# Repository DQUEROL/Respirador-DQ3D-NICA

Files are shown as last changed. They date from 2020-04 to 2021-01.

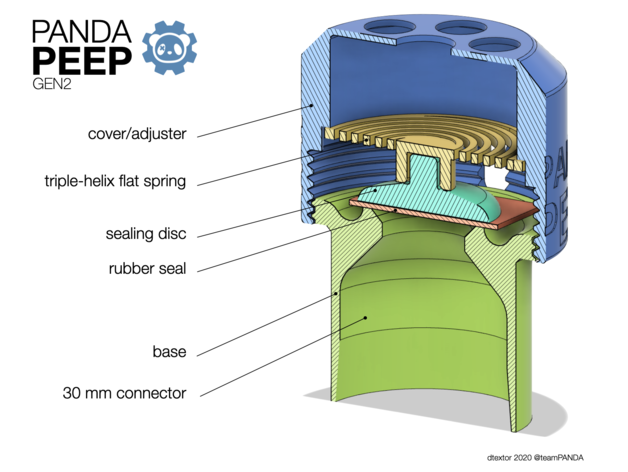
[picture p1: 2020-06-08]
03 Accesorios, valvulas, sensores/peep/PANDApeep+Gen2+PEEP+valve/images/PANDApeep_gen2.png

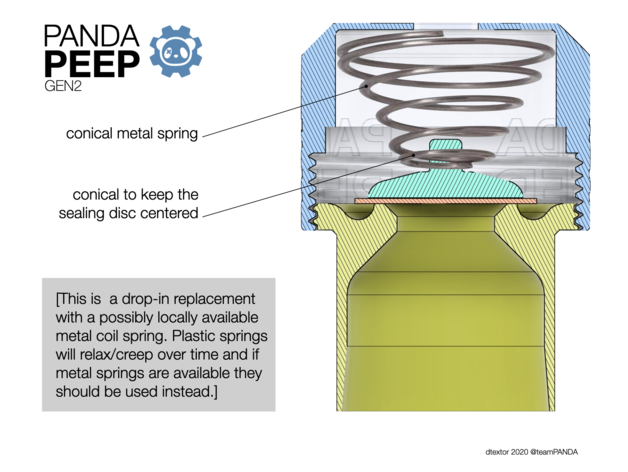
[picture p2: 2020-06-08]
03 Accesorios, valvulas, sensores/peep/PANDApeep+Gen2+PEEP+valve/images/Screenshot_2020-04-04_at_11.43.28.png

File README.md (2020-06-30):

# Apoyo respiratorio DQ3D para CoViD-19

Daniel Querol

Nicaragua, 28 04 2020

(https://www.youtube.com/watch?v=0zzoeBUPshY)

## El porqué de este Respirador

Nicaragua es el segundo país más pobre de América, y tiene un sistema de salud que, a falta de recursos, funciona con una mezcla de sobreesfuerzo del personal médico y mecanismos folclóricos para enfrentar patologías.

Frente a la COVID-19 y con recursos muy limitados, el gobierno ha asumido una posición fatalista para el conjunto de la población. Hasta la fecha se han reportado trece casos. Al igual que en el resto del mundo, es de esperarse que, con la curva epidemiológica conservadora planteada por el MINSA, en Nicaragua se presentarán al menos 32,000 casos en los próximos 180 días, de los cuales 8,000 serán graves y pasarían a cuidados intensivos. En todo el país hay menos de 150 respiradores, la mayor parte de los cuales están reservados. No se conoce de un plan de compra de respiradores, y tampoco existe el personal capacitado para manejarlos.

Los primeros análisis médicos estiman que sólo un 10 a 20% de los pacientes sometidos a intubación mecánica consigue recuperarse, y con secuelas a corto y largo plazo.

En la coyuntura actual parece razonable construir algún tipo de respirador que permita **respiración asistida** , ya que la **respiración controlada** incluye sedación, intubado y monitoreo, lo cual sólo puede ser hecho por un médico preparado y en condiciones hospitalarias. 

Para las condiciones de Nicaragua y de muchos otros países pobres, es necesario diseñar un equipo que permita dar respiración asistida (sin necesaria supervisión médica directa, por ejemplo vía telemedicina) y cuyos costos sean bajos, que sea robusto y con componentes fácilmente disponibles.
El equipo actualmente se puede considerar de la categorìa **BiPAP**.

## Estructura de directorios

[Descripción completa del equipo y proceso de seleccion de caracteristicas y componentes](https://github.com/DQUEROL/Respirador-DQ3D-NICA/blob/master/Equipo%20apoyo%20respiratorio%20v2.docx)

[00 Diseño](https://github.com/DQUEROL/Respirador-DQ3D-NICA/tree/master/00%20Dise%C3%B1o)            Piezas para corte laser e impresion 3D

[01 AMBUs](https://github.com/DQUEROL/Respirador-DQ3D-NICA/tree/master/01%20AMBUs)             Diferentes modelos de AMBU utilizados en proyectos

[02 Motores y driver](https://github.com/DQUEROL/Respirador-DQ3D-NICA/tree/master/02%20Motores%20y%20driver)  Motores utilizados y caracteristicas

[03 Accesorios, valvulas, sensores](https://github.com/DQUEROL/Respirador-DQ3D-NICA/tree/master/03%20Accesorios%2C%20valvulas%2C%20sensores) Informaciòn de los sensores revisados y utilizados, incluye PEEP.

[04 Electronica](https://github.com/DQUEROL/Respirador-DQ3D-NICA/tree/master/04%20Electronica%20y%20firmware)       **Diseño y sketch Arduino**

[05 Fotos y Videos ](https://github.com/DQUEROL/Respirador-DQ3D-NICA/tree/master/05%20Fotos%20y%20videos)

[06 Revisiones y Testing](https://github.com/DQUEROL/Respirador-DQ3D-NICA/tree/master/06%20Revisiones%20y%20Testing)   **Ultimas actualizaciones**

[Información clínica](https://github.com/DQUEROL/Respirador-DQ3D-NICA/tree/master/Informacion%20clinica)

[Manuales de otros ventiladores y respiradores](https://github.com/DQUEROL/Respirador-DQ3D-NICA/tree/master/Manuales%20de%20ventiladores%20y%20respiradores)

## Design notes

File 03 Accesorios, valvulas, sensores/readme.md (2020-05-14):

Sensores

Presion
https://www.allaboutcircuits.com/technical-articles/electrical-engineer-using-pressure-sensor-adjust-oxygen-concentration-mechanical-ventilation/

Volumen y flujo
Pressure Airflow Measure Device with Analog Sensor - Arduino Project Hub
https://create.arduino.cc/projecthub/itmightbeworse/pressure-airflow-measure-device-with-analog-sensor-037d15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

Humedad, temperatura y presión	BMP280

Gauge & Differential Pressure Sensors SMI
https://www.mouser.com/datasheet/2/589/SM6X21_Datasheet-1287040.pdf

Humedad y temperatura	DHT22
	
Biomonitor

  Pulso, Oxigenación, Temperatura

Valvulas
Download free 3D printer designs ventilator valves 3d model � Cults
https://cults3d.com/en/3d-model/gadget/ventilator-valves-3d-model-shawnshroff

Interfases (pantallas y encoders)
Encoder Library, for Measuring Quadarature Encoded Position or Rotation Signals
https://www.pjrc.com/teensy/td_libs_Encoder.html

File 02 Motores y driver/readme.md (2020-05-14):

Links anotados

5X CNC Single Axis 4A TB6600 24 Phase Hybrid Stepper Motor Drivers Controller eBay
URL=https://www.ebay.com/itm/5X-CNC-Single-Axis-4A-TB6600-2-4-Phase-Hybrid-Stepper-Motor-Drivers-Controller/133288683688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

TB6600 Stepper Motor driver Tester - Hackster.io
https://www.hackster.io/ashleyblack/tb6600-stepper-motor-driver-tester-85a29e

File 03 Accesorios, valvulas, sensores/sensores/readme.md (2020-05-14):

Links anotados

Ideas basicas
https://hackaday.io/project/170782-precision-ventilator
https://derangedphysiology.com/main/cicm-primary-exam/required-reading/respiratory-system/Chapter%20509/sensors-monitoring-mechanical-ventilation

Paquete para montaje
https://hackaday.io/project/170622-visp-ventilator-inline-sensor-package

Flow Sensor Solutions in Modern Medical Ventilators 
Sensirion
https://www.sensirion.com/en/about-us/newsroom/sensirion-specialist-articles/flow-sensor-solutions-in-modern-medical-ventilators/

AMPHENOL
https://www.piher.net/sensors/index.php?Itemid=1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

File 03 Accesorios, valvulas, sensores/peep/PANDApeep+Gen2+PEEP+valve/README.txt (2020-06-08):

PANDApeep Gen2 PEEP valve by dtextor on Thingiverse: https://www.thingiverse.com/thing:4250354

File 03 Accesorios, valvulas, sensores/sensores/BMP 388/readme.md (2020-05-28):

Links anotados

Comparacion de sensores sencillos
https://randomnerdtutorials.com/dht11-vs-dht22-vs-lm35-vs-ds18b20-vs-bme280-vs-bmp180/

https://goughlui.com/2018/08/05/note-bosch-sensortec-bmp280-vs-bme280-sensor-confusion/

USO del BMP280
Para usar dos sensores BMP280 en I2C, la direccion es 0x76 normalmente (SDO = 0v) y 0x77 cuando se conecta SDO a 3.3v.

https://github.com/snipe75/low-cost-medical-ventilator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

https://www.bosch-sensortec.com/products/environmental-sensors/pressure-sensors/pressure-sensors-bmp280-1.html

https://www.esp8266.com/viewtopic.php?f=13&t=18141&start=8

Uso en Arduino, BME280 non blocking
https://github.com/finitespace/BME280#settings

An Arduino compatible, non-blocking, I2C/SPI library for the Bosch BMP280 barometer.
https://github.com/MartinL1/BMP280_DEV

Next generation BMP388
https://www.mouser.com/datasheet/2/783/BST-BMP388-DS001-1509617.pdf

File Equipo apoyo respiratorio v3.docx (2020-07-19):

Apoyo respiratorio DQ3D para Covid-19

DQ3D-NICA BiPAP

Daniel Querol

Nicaragua, 28 05 2020

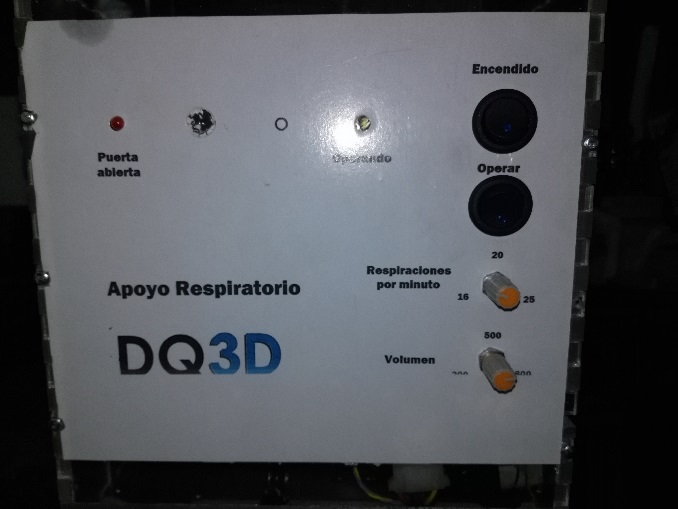
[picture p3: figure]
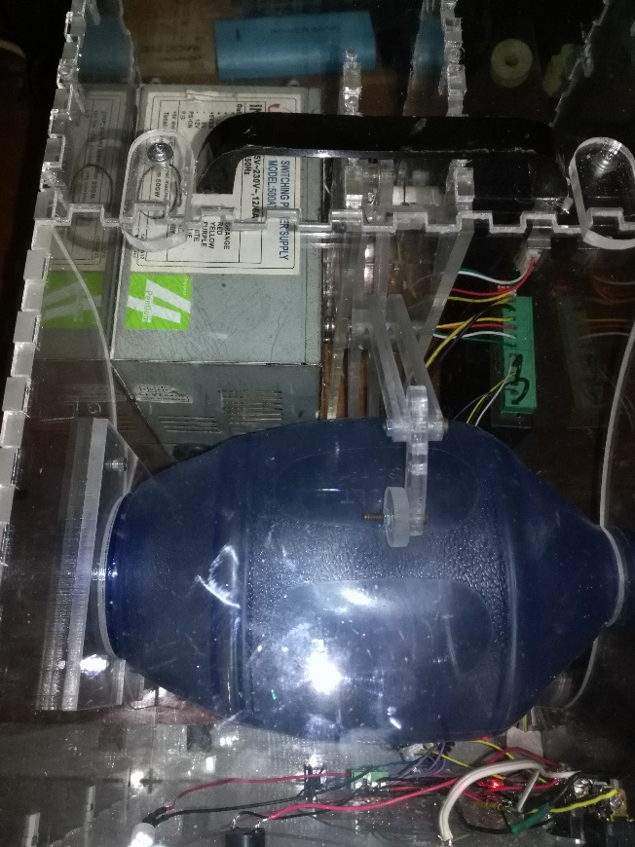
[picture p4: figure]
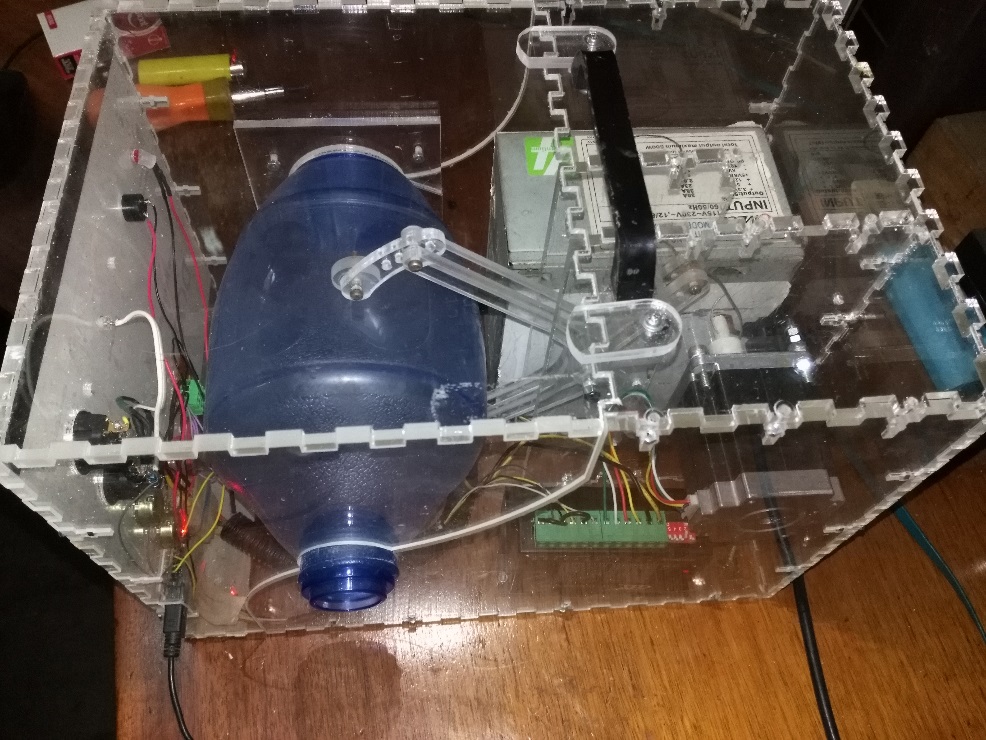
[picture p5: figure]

Contenido

# 1 Conceptos y objetivos

## 1.1 El porqué de este Respirador

Nicaragua es el segundo país más pobre de América, y tiene un sistema de salud que, a falta de recursos, funciona con una mezcla de sobreesfuerzo del personal médico y mecanismos folclóricos para enfrentar patologías.

Frente a la COVID-19 y con recursos muy limitados, el gobierno ha asumido una posición fatalista para el conjunto de la población. Hasta la fecha se han reportado trece casos. Al igual que en el resto del mundo, es de esperarse que, con la curva epidemiológica conservadora planteada por el MINSA, en Nicaragua se presentarán al menos 32,000 casos en los próximos 180 días, de los cuales 8,000 serán graves y pasarían a cuidados intensivos. En todo el país hay menos de 150 respiradores, la mayor parte de los cuales están reservados. No se conoce de un plan de compra de respiradores, y tampoco existe el personal capacitado para manejarlos.

Los primeros análisis médicos [^1], [^2], [^3] estiman que sólo un 10 a 20% de los pacientes sometidos a intubación mecánica consigue recuperarse, y con secuelas a corto y largo plazo.

En la coyuntura actual parece razonable construir algún tipo de respirador que permita respiración asistida (BiPAP) , ya que la respiración controlada incluye sedación, intubado y monitoreo, lo cual sólo puede ser hecho por un médico preparado y en condiciones hospitalarias.

Para las condiciones de Nicaragua y de muchos otros países pobres, es necesario diseñar un equipo que permita dar respiración asistida (sin necesaria supervisión médica directa, por ejemplo vía telemedicina) y cuyos costos sean bajos, que sea robusto y con componentes fácilmente disponibles.

## 1.2 Selección de componentes

En base a lo anterior, se diseñó un equipo basado en componentes reciclados disponibles de impresoras y computadores, con una estructura de soporte hecha en acrílico cortado con láser, pero que podría hacerse con madera contrachapada.

Hay muchos prototipos creados por cientos de voluntarios en todo el mundo, de los cuales se retomaron ideas y conceptos, en un verdadero esfuerzo de colaboración internacional. Se analizaron varios prototipos preexistentes (Anexo 1) de una lista mundial de procesos de trabajo (https://docs.google.com/spreadsheets/d/e/2PACX-1vTYAfldxoIiO46VAWH1NlhrwFBn9mguqS2bh1spnLEu4AVVN1cj1vaEm6vOp5Z6UnaAbUwd8dslCXdM/pubhtml).

Durante la fase de selección de opciones a inicios de marzo, se valoraron las propuestas planteadas y se tomaron algunas decisiones:

- Los componentes deben ser económicos y de fácil disponibilidad.
- Las piezas mecánicas y estructurales adicionales deben ser cortadas y no impresas en 3D, ya que las impresoras 3D no están disponibles para todos, todavía.
- Los motores de limpiaparabrisas para presionar el AMBU usados en muchos diseños tienen mucha fuerza, pero no están diseñados para uso continuo durante días.
- Los diseños con uso de levas (discos) excéntricas no permiten regular volumen variable de aire.
- La velocidad y posición de motores clásicos (AC y DC) no pueden ser controlados con precisión. Y no se pueden mantener con fuerza en un punto fijo (Meseta).
- El uso de una caja de cambios o reductor de velocidad hace más difícil la producción de componentes o más alto el costo. Los motores con caja incorporada no son de fácil ubicación.
- Hay que minimizar el desperdicio de potencia, para poder reducir el tamaño del motor. Para ello:
  - La presión sobre el AMBU debe ser bilateral y simétrica.
  - Se deben minimizar las pérdidas de energía durante la transmisión
  - El ángulo de ataque de la pieza de presión determinará su buen funcionamiento

### 1.2.1 Componentes y conceptos utilizados

(Ver Anexo 2: detalles técnicos)

Componentes y conceptos utilizados (ver lista con detalles técnicos) Componente | Link | Tipo | Notas
Resucitador Ambulatorio AMBU | | Nuevo | 1
Fuente de poder | ATX-PSU de PC (https://en.wikipedia.org/wiki/Power_supply_unit_(computer)) | Reciclado | 2
Motor de pasos NEMA23 | 2.4 A, 13.9Kg.cm (1.36Nm) (https://www.ebay.com/itm/New-Nema-23-Stepper-motor-Sanyo-Denki-142-ozin-CNC-ROUTER-MILL-LATHE-ROBOT-0666/121701679248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) | Reciclado | 3
Arduino Nano | Nano (https://www.ebay.com/itm/Mini-USB-Nano-V3-0-ATmega328P-5V-16M-Micro-Controller-Board-for-Arduino/174120707751) | Nuevo | 4
Driver Motor | 5 Amp TB6600 (https://www.ebay.com/itm/CNC-Single-Axis-TB6600-0-2-5A-Two-Phase-Hybrid-Stepper-Motor-Driver-Controlle/254581090595) | Nuevo | 5

Notas

1. Resucitador (respirador) Ambulatorio AMBU (chimbomba)

Descripción Adulto

Volumen tidal 700 ml

Peso del paciente > 30 kg

Volumen total de la bolsa 1475 ml

Dimensiones (longitud x diámetro) 291 mm x 128 mm

Volumen de la bolsa del depósito de O2 2600 ml

Conector externo del paciente 22 mm (ISO)

Conector interno del paciente 15 mm (ISO)

Conector espiratorio (para válvula PEEP) 30 mm macho (ISO)

- Apretando con una mano 650ml, 110mm
- Ambos lados 800ml, 120mm
- AMBU son 128mm a 131 mm de diámetro en modelos en línea
2. Las fuentes de poder ATX son utilizadas en la mayor parte de las computadoras, y son de fácil disponibilidad, económicas, robustas y estables. Además tienen 5v y 12v.
3. El motor de pasos NEMA23 se encuentra en muchos equipos de oficina, son potentes y robustos, y permiten control preciso de posición y velocidad.
4. El Arduino Nano, tiene suficiente memoria y capacidad de procesamiento para este equipo, siendo muy económico y robusto.
5. Estos driver son de fácil disponibilidad y económicos.

# 2 Especificaciones clínicas del Respirador DQ3D-NICA

## 2.1 Recomendaciones clínicas del Dr. Karil Barquero

  - Frecuencia: 16 a 25 respiraciones por minuto (rango continuo)
    - Buscar mecanismo para sincroniza con respiración del paciente
      - 30 por minuto hiperventilando, sedar, diazepan, de allí declinar
  - Tiempo relativo del ciclo aspira/espira: 1:1 – 1:3
    - Finalmente, fracción inspiratoria de .42
  - Volumen marea regulable de 200 a 700 cc
  - Válvula mecánica sobrepresión 40 a 60 cm.H2O
  - Alarma
  - Posibilidad de extracción rápida para manejo manual
  - Sensores Temperatura, Humedad Relativa
    - Temp max : 40 C
    - HR: min 32%, max 50%
  - Sensores de presión si se puede

## 2.2 Otros datos

Se retomaron las especificaciones mínimas de MIT. (https://e-vent.mit.edu/clinical/key-ventilation-specifications/)

Se utilizó el trabajo de Chaparro y Giraldo (2011)[^4] para para la determinación de valores óptimos, para una buena recuperación.

Variables respiratorias (http://www.scielo.org.co/scielo.php?script=sci_arttext&pid=S1909-97622011000100007&lng=en&nrm=iso&tlng=es) | | Mejor | Unidad
duración del ciclo respiratorio | TTot | 2.79 | s
tiempo de inspiración | TI | 1.09 | s
tiempo de espiración | TE | 1.69 | s
volumen tidal | VT | 622 | cc
fracción inspiratoria | TI/TTot | 0.42
flujo inspirado medio | VT/TI | 629 | cc/s
índice de respiración superficial | f/VT | 70 | Resp/min/l | siendo f la frecuencia respiratoria

# 3 Equipo de apoyo respiratorio

El equipo propuesto, en su versión 3.0, tiene las siguientes características:

Función | Rango | Cambiable vía | Fijada
Volumen aire | 200 a 600 cc | Tablero | No
Respiraciones por minuto | 16 a 25 RPM | Tablero | No
Fracción inspiratoria | 0.42 | Firmware | Si
Meseta | 500 milisegundos | Firmware | Si
Pausa al final marea | 0 | Firmware | Si
Medición de presión y temperatura | Cada 100 milisegundos | Firmware | Si
Válvula mecánica sobrepresión | 35cmH2O | NO | Si
Salto de pasos por sobrepresión | 30cmH2O | NO | SI
Conexión a oxigeno | Disponible
Alarmas | varias fallas mecánica, presión, etc
1= falla de motor/origen, | pasos | Firmware | Si
2= Falla de origen del brazo, | pasos | Firmware | Si
3= Exceso de presión | 30cmH2O | Firmware | Si
4= Presión demasiado baja | -5cmH2O | Firmware | Si
5= Sobre temperatura | 39C | Firmware | Si
6= Sensor presión desconectado | | Firmware | Si

La conexión del equipo a la mascarilla se hace, dependiendo de la manguera disponible, con dos adaptadores impresos en 3D. En Nicaragua solo se obtuvo una manguera de PVC de 19mmØ, utilizada para cableado interno en construcciones.

La extracción del AMBU para uso manual es sencilla.

No hubo calentamiento durante las 192 horas continuas que el equipo estuvo funcionando, por lo que la temperatura no necesita ser controlada.

La humedad del aire, de ser necesario, puede ser aumentada con el uso de un frasco con agua en la manguera entre el equipo y la mascarilla.

## 3.1 Lógica de operación

El usuario enciende el equipo, y se inician calibraciones y definición de punto de origen

El usuario enciende el apoyo respiratorio (Operar). El equipo lee los valores de volumen y RPM e inicia la respiración. Después de cada respiración se actualizan los valores anteriores, si el usuario los modificó y se recalibra el motor si hubo salto de pasos.

Constantemente se monitorean posibles fallas mecánicas. De ser necesario, se encienden indicadores y la alarma, que pueden ser apagados con un botón de reseteo.

## 3.2 Pendientes

### 3.2.1 Interfaz

Una pantalla mejoraría la interfaz con el usuario, pero la búsqueda de un sistema sencillo (y la falta de ciertos componentes…) no permitió incluirla en este primer modelo. Hay dos opciones:

- Usar un Arduino más grande (Mega o Uno), con una conexión en serie a la pantalla
- Mantener el Arduino Nano con una interfaz I2C a la pantalla

### 3.2.2 Biomonitoreo

# 4 Agradecimientos

El autor desea agradecer a

- Ramiro Gonzales, por su apoyo con las múltiples versiones de corte en acrílico.
- Dr. Karil Barquero, por haber apoyado esta idea, no solo con sus conceptos clínicos, sino con su optimismo.
- Dra. Largaespada, por seguir buscando soluciones.
- Rubén Valiente y Reinaldo Erlach apoyaron con ideas e impulso.

# 5 Anexos

## 5.1 Anexo1: Conceptos analizados

Link | https://gitlab.com/open-source-ventilator/OpenLung/-/tree/master/mechanical-concepts | Manejo mecanico del respirador | Eliminado por | Motor | Piezas impresas

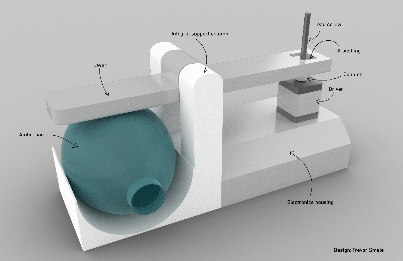
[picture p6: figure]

https://gitlab.com/open-source-ventilator/OpenLung/-/tree/master/mechanical-concepts/_retired-concepts/ventilator-concept-1 | | Palanca | Presion sobre motor y problemas control | Nema17 | Muchas

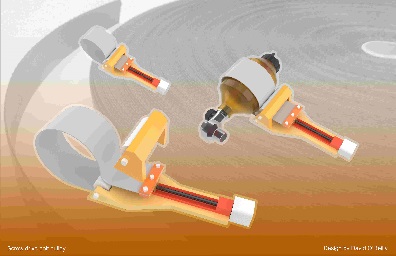
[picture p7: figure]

https://gitlab.com/open-source-ventilator/OpenLung/-/blob/master/mechanical-concepts/_retired-concepts/ventilator-concept-5/feedback.md | | Keeping the screw drive, to a simpler nylon belt | | | Muchas

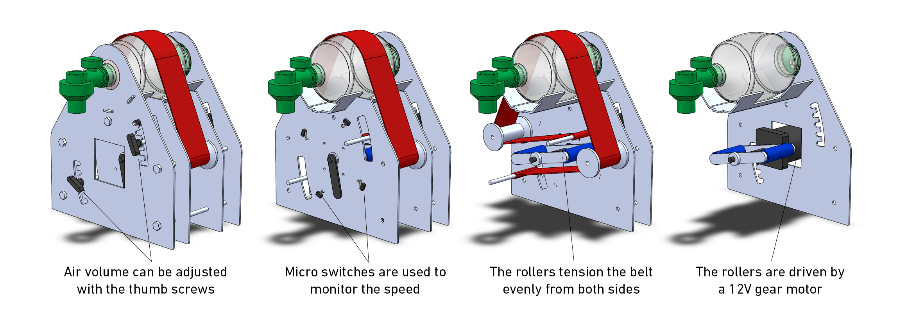
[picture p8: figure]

https://gitlab.com/open-source-ventilator/OpenLung/-/tree/master/mechanical-concepts/ventilator-concept-6 | | | | Geared motor

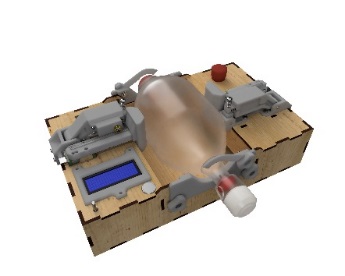
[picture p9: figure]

http://oedk.rice.edu/apollobvm/ | | | | Doble nema23 con caja de cambio
https://devpost.com/software/diy-beatmungsgerat | | | | Iteration #6 des Open Source Ventilator (OSV) | https://github.com/DIY-Beatmungsgerat/diy-beatmungsgeraet

## 5.2 Anexo 2: Lista de componentes utilizados

Parte | Especificación | Cantidad | Origen | Precio | Nota
Aire
Resucitador Ambulatorio AMBU | | 1 | Nuevo | $35.00
Conectores (como punto instalación de sensores) | Impreso 3D ABS | 2 | Nuevo | $1.00
Manguera extensión | Manguera cableado | 1m | Construcción | $1.00
Electronica
Fuente de poder | ATX-PSU de PC (https://en.wikipedia.org/wiki/Power_supply_unit_(computer)) | 1 | Reciclado | $0.00
Motor NEMA23 | 2.4 A, 13.9Kg.cm (1.36Nm) (https://www.ebay.com/itm/New-Nema-23-Stepper-motor-Sanyo-Denki-142-ozin-CNC-ROUTER-MILL-LATHE-ROBOT-0666/121701679248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) | 1 | Reciclado | $0.00
Arduino Nano | Nano (https://www.ebay.com/itm/Mini-USB-Nano-V3-0-ATmega328P-5V-16M-Micro-Controller-Board-for-Arduino/174120707751) | 1 | Nuevo | $3.12
Driver Motor | 5 Amp TB6600 (https://www.ebay.com/itm/CNC-Single-Axis-TB6600-0-2-5A-Two-Phase-Hybrid-Stepper-Motor-Driver-Controlle/254581090595) | 1 | Nuevo | $8.00
Switch encendido | | 2 | Reciclado | $2.00
Rheostato | 10kΩ | 2 | Reciclado | $0.00 | controles
Sensor óptico | | 1 | Reciclado | $0.00 | motor
Zumbador | | 1 | Reciclado | $0.00
Switch mecánico | | 1 | Reciclado | $0.00 | cierre
Sensor Presión y temp | BMP280 | 1 | | $4.00
Resistencias | 5kΩ | 2
| 470Ω | 1
Led | Rojo | 1 | Reciclado | | Falla
| Verde | 1 | Reciclado | | Operando
Caja con mecanismo | Acrílico 5mm | 1 | Corte Laser | $52.00 | 1
Eje tracción | ABS | 1 | Impreso | $0.50
Pernos M3 con tuerca | 15mm | 52 | | $5.00 | Se pueden usar menos
| 20mm | 4 | | | Brazo
| 50 mm | 2 | | | Mecanismo
| 10 mm (autoroscante) | 3 | | | Seguros
Pernos M4 con tuerca | 50mm | 1 | | | Eje
| 10 mm | 4 | | | Fuente
| 20mm | 4 | | | Motor
Manija | 4 pulgadas entre centros | 1 | | $1.00
Hules base | 3mm espesor min | 4 | Reciclado | $0.00 | pegados
Varios
Nylon de pesca industrial trenzado #24 (Solo torcido se deshilacha!!) | 1.3 a 1.8mm | 30cm | | $0.00 | Mecanismo
Cinta adhesiva ancha | | 20cm | | $0.00 | Bisagra
Cianoacrilato | | | | $2.00
Cinta eléctrica o tubo para cableado | | | | $2.00
| | | Costo total | $116.12

Nota: 1. Se calculó sobre la base de 110US por lámina de Acrílico de 5mm y 30US por hora de corte laser.

[^1] https://www.thelancet.com/journals/lancet/article/PIIS0140-6736(20)30566-3/fulltext
[^2] https://jamanetwork.com/journals/jama/fullarticle/2765184
[^3] https://www.sciencemag.org/news/2020/04/survivors-severe-covid-19-beating-virus-just-beginning
[^4] http://www.scielo.org.co/scielo.php?script=sci_arttext&pid=S1909-97622011000100007&lng=en&nrm=iso&tlng=es

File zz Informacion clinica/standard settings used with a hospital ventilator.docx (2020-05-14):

Michael Silsbury Here are some standard settings used with a hospital ventilator when a patient is intubated:

INITIAL SETTINGS

* Volume per Breath = no less than 6 ml/kg of predicted body weight; no more than 8 ml/kg of predicted body weight

Predicted body weight is based on a patients height.

This is the chart to calculate predicted body weight:

http://www.ardsnet.org/files/pbwtables_2005-02-02.pdf

Volume per breath must be configurable by health care provider; increments of 100 ml is probably acceptable as long as volume per breath falls within 6-8 ml/kg

* Breaths per minute = 10 - 20 breaths/ minute

The must be configurable by health care provider. Increments of 1 breath per minute is required

Note: practioner’s goal is to deliver a total volume per minute (volume per breath x breaths per minute).

If the volume per breath is on the high end, the breaths per minute can be dropped to achieve the target volume per minute objective.

In other words there is some wiggle room that’s acceptable in both these settings for a particular patient because the other setting can compensate for it.

* Minimum air pressure provided to patient at trough of breathing (exhalation): 0 - 25 cmH2O (most common setting for Covid 19 appears to be starting at 5 cm H2O working up to 15 cm h2O)

Must be medical provider configurable, ideal would be in 1 cm H20 increments, 2.5 cm H2O would be the largest acceptable increment.

(This setting keeps “lungs” from “collapsing” during exhalation)

* need an oxygen intake port that can handle 40 - 60L oxygen at 100% concentration which is usually delivered from the hospital wall.

Oxygen at the source is always 100%.

100% oxygen can be mixed with atmospheric air, which is 21% oxygen, in ratio to get desired level of oxygen that the patient needs.

Oxygen concentration that the patient receives usually starts at 100% and dropped to the lowest level possible that provides adequate oxygen in the blood and adequate carbon dioxide range in the blood. A medical provider will draw blood approximately every 30 minutes when tweaking ventilator settings to get the settings right for the patient.

Hospital ventilators have two modes:

Mode 1: Dr sets the desired volume per breath, ventilator uses as much pressure as needed to deliver the volume. (A compromised lung will require more pressure to “inflate” than a healthy one). This is known as “volume mode”

Mode 2: Dr sets target pressure for ventilator to reach, regardless of volume per breath. This is known as “pressure mode”

volume based mode is used more often than pressure based mode.

A ventilator that delivers a fixed volume of air per breath must also have a sensor to indicated how much pressure was needed to deliver the breath.

This is important as both a safety and diagnostic tool.

This peak pressure used to deliver the inhalation breath if too high for too long can damage the lungs. If pressure needed to deliver a set volume is increasing this has diagnostic relevance to the doctor and is key to monitoring the patient

In volume based mode, the pressure needed to deliver the inhalation is a reporting feature.

In pressure based mode, the pressure level is a user configurable setting.

Safe level of peak pressure is general less than 35 cm H2O.

When pressure exceeds this level, it’s a sign to the practitioner that patient has too much volume per minute; and prompts practioner to verify this by X-ray and usually to reduce volume per breath, or breaths per minute.

Finally it is useful for practioner to know how much pressure the system has when the system is on hold. A system pause button is useful to pause the ventilator and to determine the pressure at the end of exhalation coming from the patient. This is a nice to have feature. The other features are more important.

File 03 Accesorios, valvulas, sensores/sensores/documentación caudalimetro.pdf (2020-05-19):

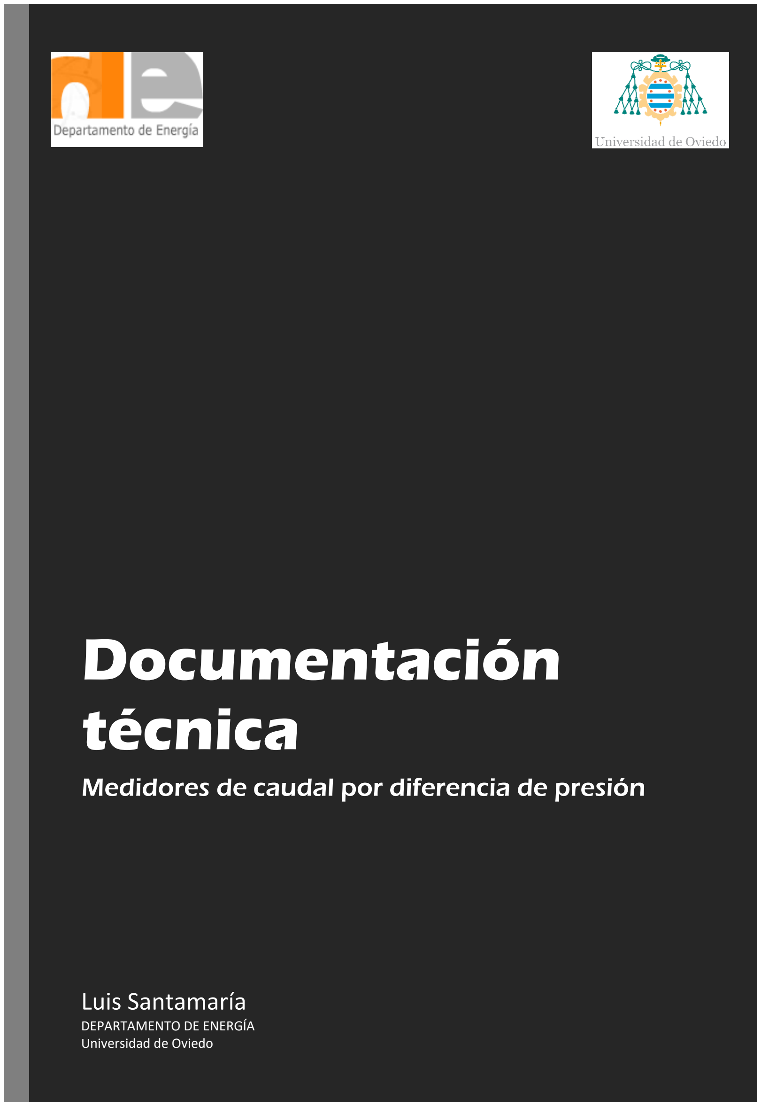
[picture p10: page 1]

# Documentación técnica

## Medidores de caudal por diferencia de presión

## Luis Santamaría

DEPARTAMENTO DE ENERGÍA
Universidad de Oviedo

## Contenido

### Objetivos:

Proveer alternativas a caudalímetros comerciales de uso médico debido a su posible escasez en el marco del COVID-19. Se busca en primer lugar, que los caudalímetros sean capaces de medir con precisión en el rango de caudales de tratamiento médico contra esta enfermedad y, en segundo lugar, que sean accesibles y de bajo coste. El objetivo de los caudalímetros propuestos no es el de sustituir a sensores comerciales, si no de suplir una posible ausencia de estos. La recomendación es que si hay sensores comerciales disponibles se opte por ellos.

### Normas de referencia:

- ISO 5167-1:2003
- ISO 5167-2:2003
- ISO 5167-4:2003
- ISO 5356-1:2015

Se declara que el uso de estas normas ha sido puramente académico y no se busca ningún beneficio económico o de otro tipo diferente al de suplir las posibles necesidades de material necesario para el bienestar de pacientes afectados por COVID-19.

### Medidores propuestos:

Se han estudiado varios diseños de medidores de caudal por presión diferencial. Para el estudio se ha tomado como referencia un rango de regulación de Volumen Tidal de 250 a 600 ml, el cual, aplicando un ciclo típico de ventilación forzada da lugar a los caudales mostrados en la Figura 1.

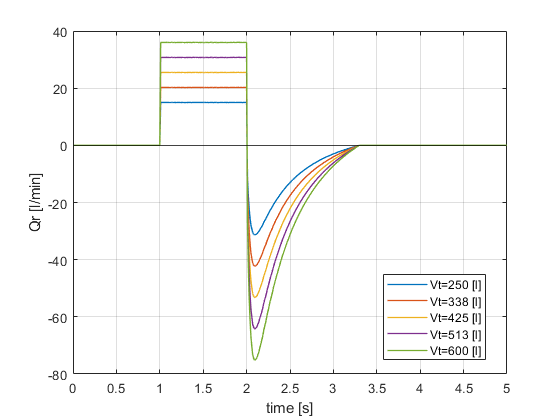
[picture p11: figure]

Figura 1: Ciclos de caudal de estudio.

De los diseños estudiados se proponen tres, que se designarán por un código de 9 caracteres separados por guiones en tres grupos de tres caracteres, el código hace referencia a lo siguiente:

- “VEN”: Principio de funcionamiento.
- “B11”: Dos posiciones decimales de la Relación de Diámetros Nominal.
- “D22”: Diámetro Mayor Nominal.

### VEN-B30-D22

### Justificación del diseño:

Este diseño se basa en el efecto Venturi. La bidireccionalidad del flujo y el rango de caudales implican que la norma ISO sobre medidores basados en este principio no se puede aplicar en este caso. No obstante, se han mantenido algunas de las relaciones geométricas como el posicionamiento y el diámetro de las tomas de presión, además de la longitud de las secciones tubulares. Se ha realizado una versión con cámaras anulares y varias tomas de presión y una más sencilla con tomas directas.

El estrechamiento y el ensanchamiento tienen ambos un ángulo de 45°. Se comprobó mediante simulación computacional de fluidos (CFD) que, debido a la naturaleza del flujo, a pesar de utilizar un ángulos convencionales de 12° el flujo no mantenía la adherencia a las paredes en el ensanchamiento. Por ello se opta por un ángulo más abrupto que permite reducir la longitud del caudalímetro sin perjuicio de su funcionamiento.

El diseño se ha realizado para su conexión directa a conos médicos macho de 22mm. En cuanto a la fabricación, el diseño está hecho para fabricación aditiva, pudiendo ser FDM una tecnología apropiada, siempre y cuando se cumplan las dimensiones. Los modelos se han realizado de forma paramétrica para poder corregir los factores de expansión.

En la Figura 2 se puede observar una vista de sección del diseño.

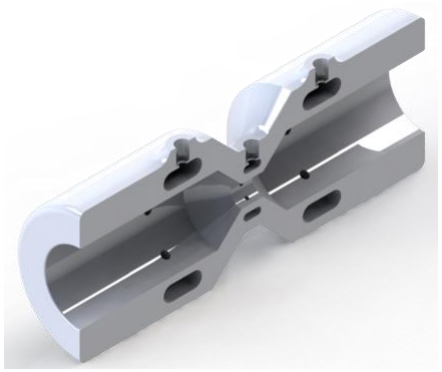
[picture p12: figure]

Figura 2: VEN-B30-D22.

### Especificaciones:

En la siguiente tabla se muestran las dimensiones más relevantes:

Dimensión: | Descripción: | Valor
D | Diámetro de la mayor de las secciones tubulares. | 21.82 mm
d | Diámetro de la menor de las secciones tubulares. | 6.5 mm
β | Relación de diámetros. | 0.298
dt | especificación del tipo de tubo neumático que precisa, diámetro exterior/diámetro interior. | 4/2 mm
C | Coeficiente de descarga estimado. | 0.887
dc | Diámetro nominal del cono médico con el que es compatible. | 22 mm

Este diseño de caudalímetro usa dos sensores de presión diferencial, conectados según el esquema de la Figura 3. La medida del caudal siempre se debe realizar entre la toma de entrada y la toma central, de forma que se utiliza el sensor 1 si el flujo entra por la zona de P1, o el sensor 2 si el flujo entra por la zona de P2.

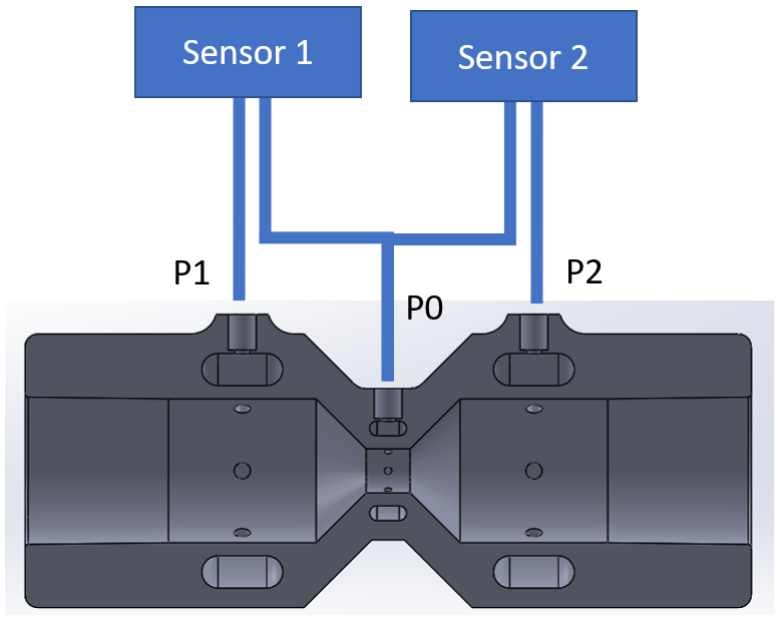
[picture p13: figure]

Figura 3: Esquema de conexiones del caudalímetro.

Las diferencias de presión estimadas para el rango de caudales de estudio y con un flujo inspiratorio entrante por P1 se pueden ver en la Figura 4, donde se muestra la diferencia de presión entre las tomas P1 y P0 hasta el segundo 2, y entre las tomas P2 y P0 del segundo 2 en adelante. Debido a la gran diferencia entre la inspiración y la expiración se propone el uso de dos sensores de presión diferenciales de rangos diferentes, concretamente uno de 250Pa para el sensor 1 y uno de 1000Pa para el sensor 2.

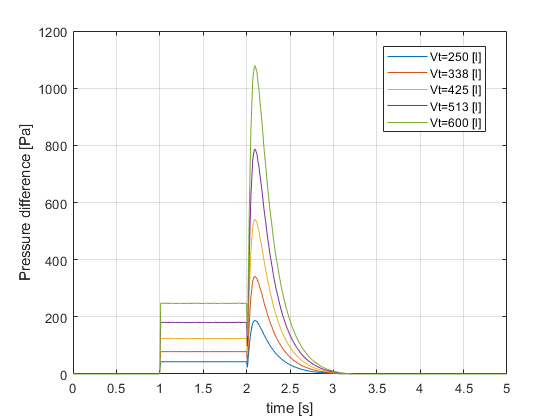
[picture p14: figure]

Figura 4: Presiones estimadas entre P0 y P1 hasta el segundo 2 y entre P2 y P0 desde el segundo 2 en adelante.

### Conclusiones:

Las ventajas de este diseño residen en la baja perturbación que produce al flujo de aire en forma de pérdidas de carga y en la buena precisión esperada utilizando sensores del rango recomendado. La principal desventaja es que precisa de dos sensores.

A pesar de contar con una aproximación sobre el valor del coeficiente de descarga, caudalímetro deberá ser calibrado tras su fabricación.

### ORI-B33-D22

### Justificación del diseño:

Se trata de un diseño basado en una placa orificio clásica con tomas en las bridas. Al igual que sucedía con el diseño del Venturi la norma ISO sobre placas orificio no contempla el uso de este instrumental para este tipo de caudales. Sin embargo, por la facilidad de fabricación y simpleza del diseño se ha propuesto una versión de este clásico instrumento.

El diseño cuenta con tres piezas independientes que se ensamblan y se fijan mediante tornillo-tuerca de métrica 4. Sería más que recomendable utilizar juntas tóricas entre las piezas para garantizar la estanqueidad. Una vez más se ha diseñado el caudalímetro para su conexión con un cono médico macho de 22mm. En la Figura 5 se puede observar una vista de sección de este diseño.

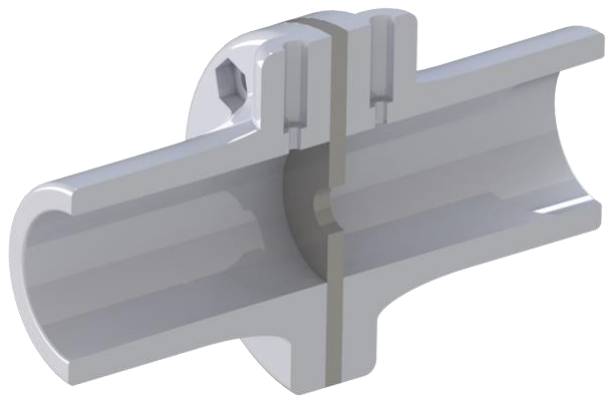
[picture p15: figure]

Figura 5: ORI-B33-D22.

### Especificaciones:

En la siguiente tabla se muestran las dimensiones más relevantes:

Dimensión: | Descripción: | Valor
D | Diámetro de la mayor de las secciones tubulares. | 21.82 mm
d | Diámetro de la menor de las secciones tubulares. | 7.6 mm
β | Relación de diámetros. | 0.333
dt | especificación del tipo de tubo neumático que precisa, diámetro exterior/diámetro interior. | 4/2 mm
dc | Diámetro nominal del cono médico con el que es compatible. | 22 mm

Este diseño de caudalímetro usa un único sensor de presión diferencial, conectado según el esquema de la Figura 6.

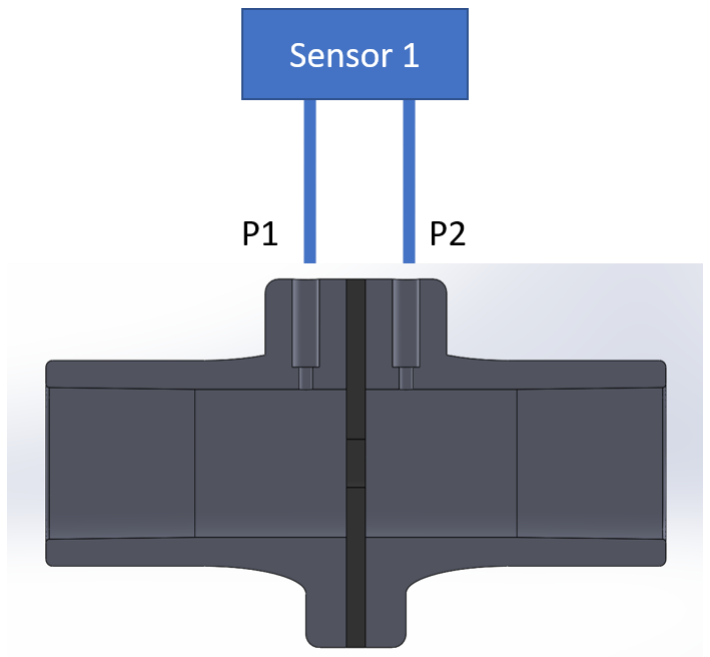
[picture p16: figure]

Figura 6: Esquema de conexión del caudalímetro.

Las presiones diferenciales estimadas para los caudales de estudio se pueden ver en la Figura 7, donde se ha representado el valor absoluto de la diferencia de presión. Como sucedía con el anterior modelo las diferencias de presión en la espiración son mucho mayores que en la inspiración. Por ello se recomienda utilizar un sensor:

- De ±1000Pa si se desea abarcar todo el rango, teniendo en cuenta que debe ser suficientemente preciso para medir bien presiones de aproximadamente 30Pa, correspondientes al menor caudal de estudio.
- De ±500Pa para abarcar la mayor parte del rango y quizás limitar el uso de este medidor a ese rango de ventilación.
- De 250Pa si únicamente se desea utilizar para medir el caudal en el inspiración.

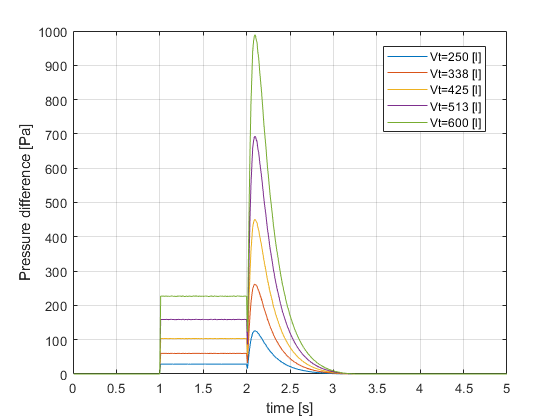
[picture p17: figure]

Figura 7: Presiones estimadas para el caudalímetro de placa orificio.

Los coeficientes de descarga estimados se muestran en la Figura 8.

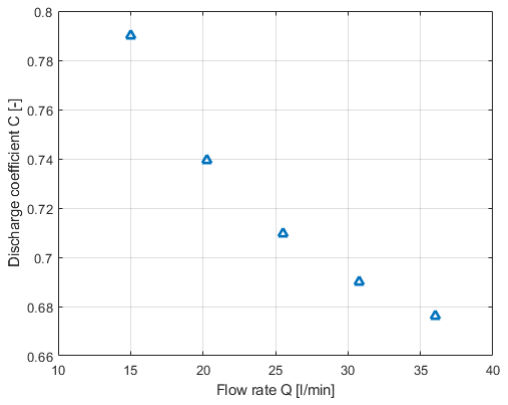
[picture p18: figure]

Figura 8: Coeficientes de descarga estimados.

### Conclusiones:

Las ventajas de este diseño son su sencillez y que con un sólo sensor diferencial de presión puede medir en los dos sentidos de caudal. La desventajas de este diseño son que requiere bastante precisión del sensor si se quiere abarcar todo el rango y que el coeficiente de descarga es variable con el caudal en el rango de caudales de aplicación. Al igual que con el caudalímetro anterior se precisa una calibración tras su fabricación.

### VOM-B37-D20

### Justificación del diseño:

Este diseño está basado en una placa orificio de sección variable con el caudal, un sistema más conocido con sus siglas en inglés VOM (Variable Orifice Meter) y que ya se utiliza en caudalímetros comerciales de aplicación médica. Existe muy poca documentación sobre este tipo de caudalímetros, así que este diseño está propuesto más bien para su desarrollo y no para su aplicación directa.

Se trata de un diseño dividido en cuatro piezas, similar al de la placa orificio, con la diferencia de que el orificio es rectangular y formado por las dos piezas centrales llamadas Flaps que son flexibles. Estos Flaps se doblan de una forma proporcional al caudal, haciendo que la relación entre la diferencia presión y el caudal sea casi lineal. Esto soluciona el problema que presentaba el caudalímetro de placa orificio anterior, ya que las diferencias de presión para los diferentes caudales son mucho menores.

En la zona de unión entre las piezas este diseño necesita juntas tóricas, ya que tiene espacio entre las partes.

En este caso, a diferencia de los anteriores, se ha optado por un diseño para conexión con cono médico hembra de 22m. En la Figura 9 se puede observar una vista de sección del diseño.

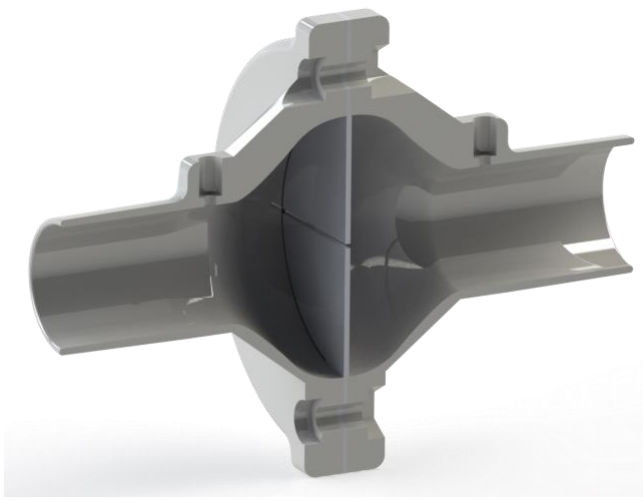
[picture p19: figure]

Figura 9: VOM-B37-D22.

### Especificaciones:

En la siguiente tabla se muestran las dimensiones más relevantes:

Dimensión: | Descripción: | Valor
D | Diámetro de la mayor de las secciones tubulares. | 19.57 mm
d | Distancia vertical entre los Flaps sin flexión. | 1 mm
L | Longitud del espacio entre los Flaps. | 20.55 mm
β | Raíz cuadrada de la relación de áreas sin flexión. | 0.368
dt | especificación del tipo de tubo neumático que precisa, diámetro exterior/diámetro interior. | 4/2 mm
dc | Diámetro nominal del cono médico con el que es compatible. | 22 mm

Este diseño, al igual que el de placa orificio utilizaría un único sensor diferencial de presión, que se conectaría como se puede observar en la Figura 10.

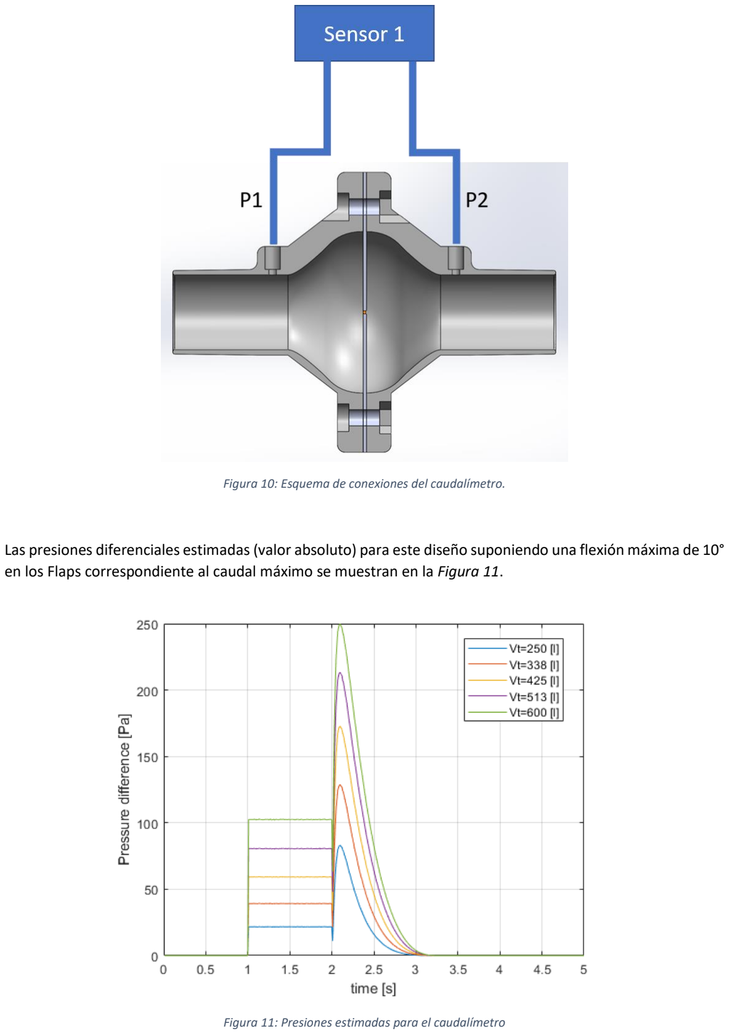
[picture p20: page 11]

Figura 10: Esquema de conexiones del caudalímetro.

Las presiones diferenciales estimadas (valor absoluto) para este diseño suponiendo una flexión máxima de 10° en los Flaps correspondiente al caudal máximo se muestran en la Figura 11.

Figura 11: Presiones estimadas para el caudalímetro

Como se puede observar en la Figura 11 el rango de presiones se reduce en considerablemente en comparación con los otros caudalímetros, de forma que con un sensor de ±250Pa se abarca todo el rango con precisión.

Además, en el rango de caudales de estudio, la respuesta del sensor se puede aproximar con precisión por una recta, como muestra la Figura 12.

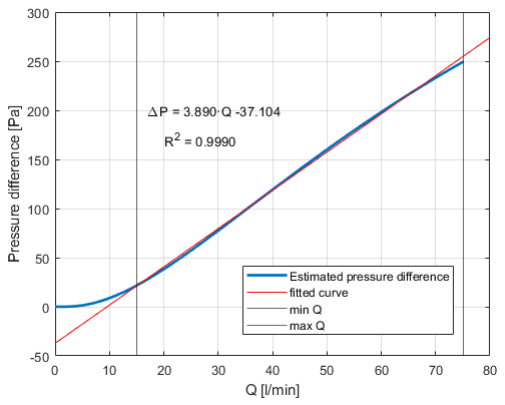
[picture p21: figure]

Figura 12: Ajuste lineal de la presión en el rango de caudales de estudio.

### Conclusiones:

Las ventajas de este diseño son que utiliza un único sensor diferencial de presión, que mide con precisión en todo el rango, y que la respuesta en el rango de caudales requerido se puede aproximar con precisión por una recta. La principal desventaja de este diseño es su complejidad, dado que los Flaps son elementos flexibles que deben tener una rigidez concreta para que el caudalímetro funcione correctamente. Además, el estudio realizado es puramente teórico. Para un correcto estudio de este diseño serían necesarios ensayos experimentales, que dadas las circunstancias no se han podido realizar. Por ello se propone como un diseño en desarrollo.

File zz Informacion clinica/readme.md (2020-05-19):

Links anotados Informacion clinica

Ventilator Mode Glossary of Terms http://www.rcjournal.com/guidelines_for_authors/glossary.cfm

ESTRUCTURA Y FUNCIONAMIENTO DEL VENTILADOR MECÁNICO.
https://www.youtube.com/watch?v=L3JfeOy8Zkw&feature=emb_rel_end

 inspiracion espiracion https://books.google.com.ni/books?id=i1YvDwAAQBAJ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

Ventilación mecánica http://www.scielo.org.pe/scielo.php?script=sci_arttext&pid=S1728-59172011000200006

TOMAR EN CUENTA 
Is protocol-driven COVID-19 respiratory therapy doing more harm than good? https://www.the-hospitalist.org/hospitalist/article/220301/coronavirus-updates/protocol-driven-covid-19-respiratory-therapy-doing

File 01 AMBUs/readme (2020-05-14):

Links anotados

Resucitadores de Silicona Laerdal (caros)
https://www.laerdal.com/es/doc/117/Resucitadores-de-Silicona-Laerdal

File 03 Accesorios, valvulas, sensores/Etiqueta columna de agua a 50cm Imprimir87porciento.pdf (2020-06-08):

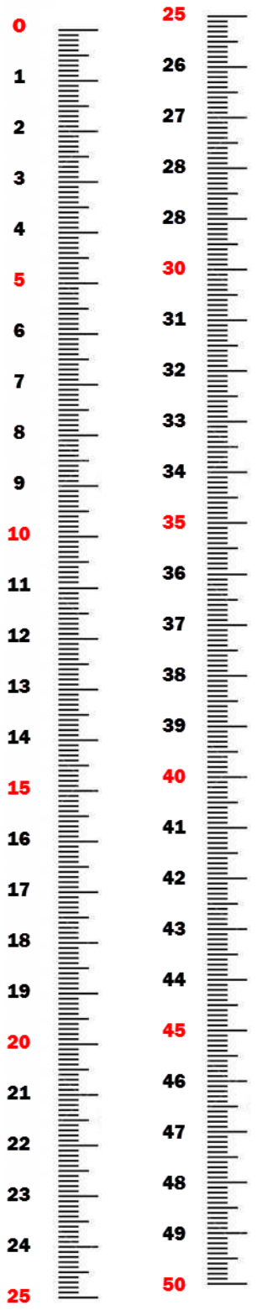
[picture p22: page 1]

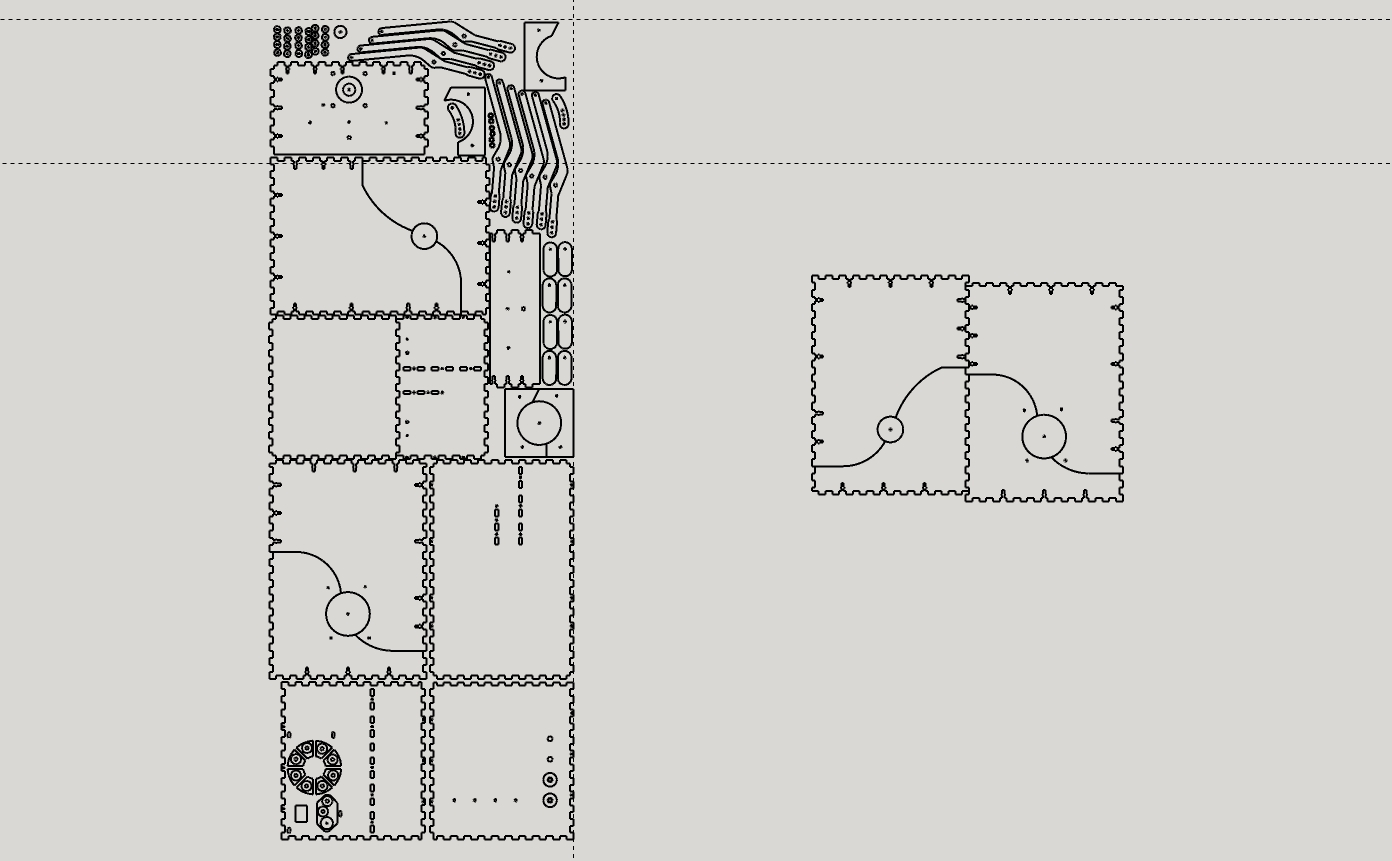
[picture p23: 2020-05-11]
00 Diseño/Respirador AMBU DQ3D v1.1 solo.jpg

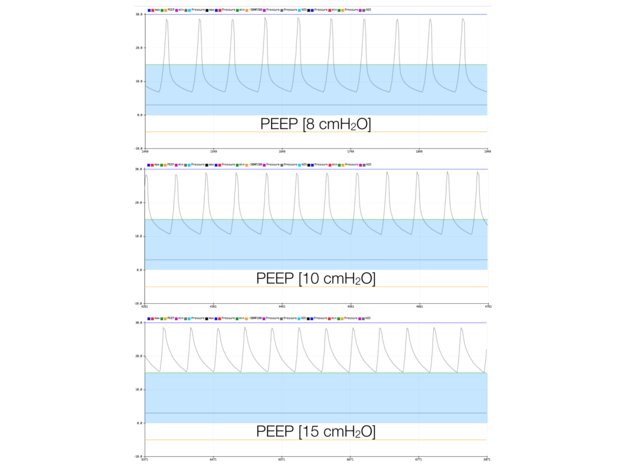
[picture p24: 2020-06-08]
03 Accesorios, valvulas, sensores/peep/PANDApeep+Gen2+PEEP+valve/images/graphs_PEEP.png

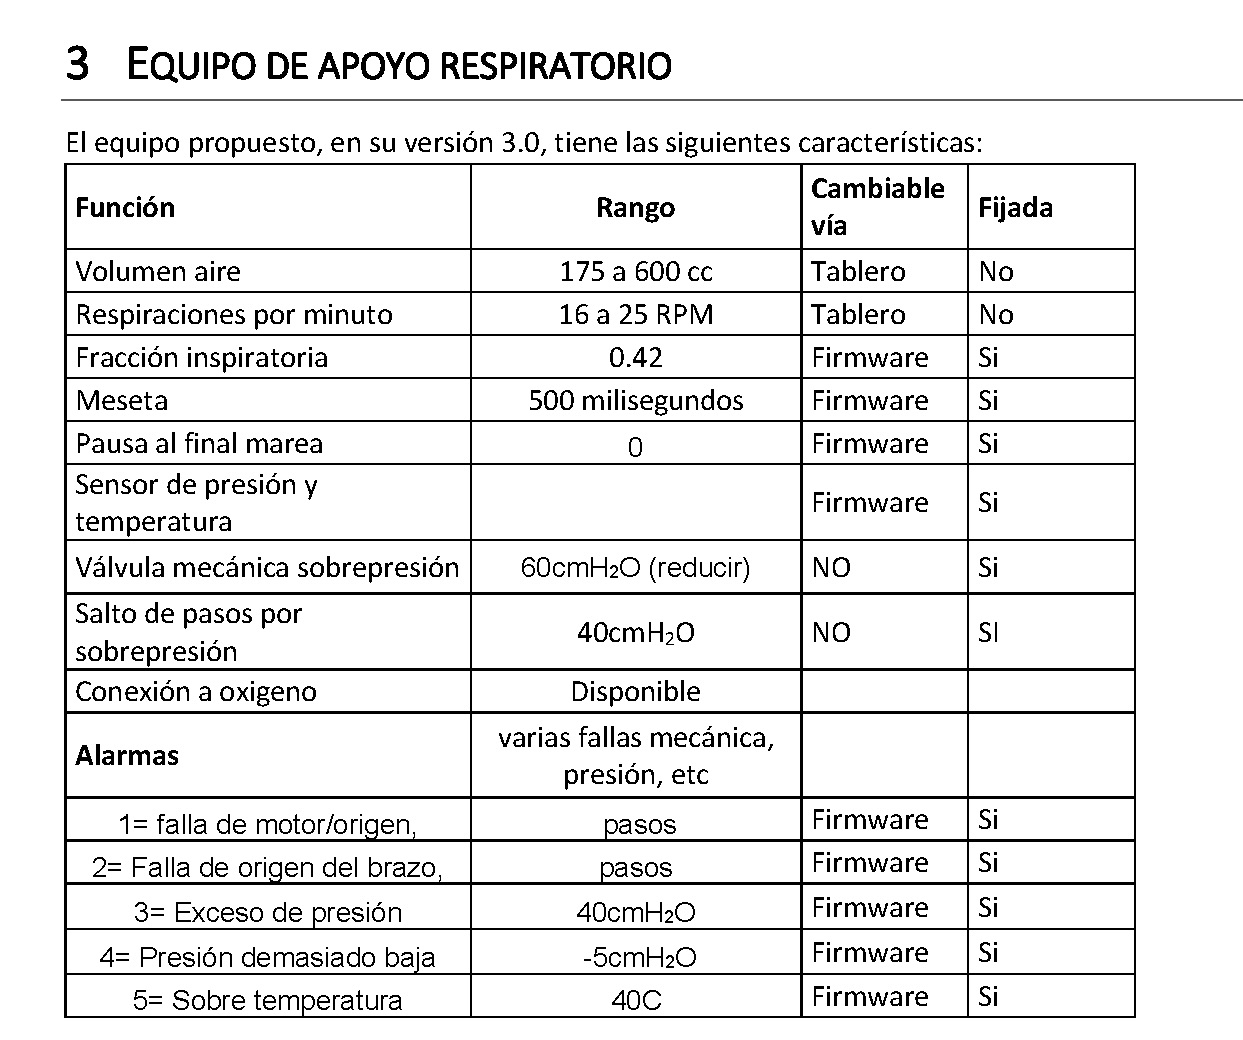
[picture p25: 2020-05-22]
Equipo apoyo respiratorio v2.jpg

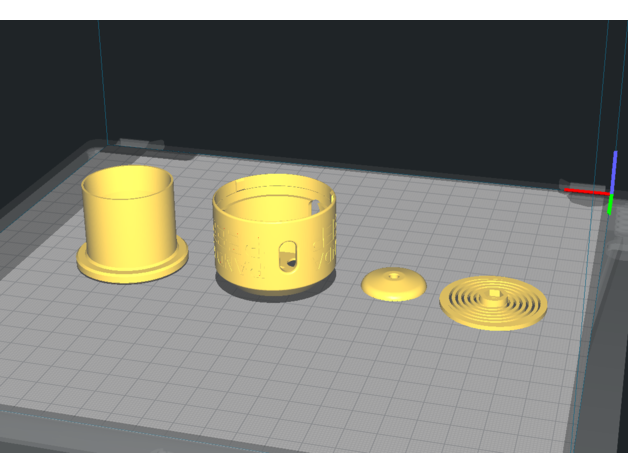
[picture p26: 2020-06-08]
03 Accesorios, valvulas, sensores/peep/PANDApeep+Gen2+PEEP+valve/images/cura_view.png

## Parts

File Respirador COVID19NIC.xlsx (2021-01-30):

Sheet: Parametros
Version 1
 | Sketch | Arduino | Tipo | Valores
 | int steps = 6; | // pin step 9 | Output
 | int direccion = 5; | // pin direccion 7 | Output
 | int potCPM; | // lectura del potenciometro de velocidad (ciclos por minuto) | Input | 8 a 40 | 60 / Ciclos por minuto= duracion ciclo en segundos
 | int boton = 7; | // pin pulsador (encendido) | Input | 1/0
 | bool activa = false; | // Logica (encendida o apagada) |  | 1/0
 | bool inhala = true; | // Logica (inhala o exhala) |  | 1/0
 | int pausa = 1000; | // Duracion de la pausa entre ciclos en milisegundos MODIFICABLE
 | int pasosMC = 2000 | //Pasos por medio ciclo (depende de mecanismo usado, 200steps per turn
 | int Tentrepasos = 1 ; | // Tiempo entre pasos para asegurar un numero de ciclos por minuto (Pausa en milisegundos, calculada) |  | (60/potCPM - pausa)*1000/ (2*pasosMC)
Version 2
 | Sketch | Arduino | Tipo | Valores | Pin
 | int alarmaPin = 2; | // Pin para activar alarma | Output |  | 2
 | int cierrePin = 3; | // Pin (endstop) para confirmar cierre de caja | Input | 1/0 | 3
 | int origenPin = 4; | // Pin para confirmar si Motor regresó a origen. No se han saltado pasos (motor en posicion adecuada) despues de un ciclo | Input | 1/0 | 4
 | int direccionPin = 5; | // pin direccion Motor | Output |  | 5
 | int pasosPin = 6; | // pin step pasos Motor | Output |  | 6
 | int botonPin = 7; | // pin pulsador (encendido) | Input | 1/0 | 7
 | int enablePin = 8; | // pin activa y desactiva motor Motor | Output | 1/0 | 8 | 2.4
 | int potCPM; | // lectura del potenciometro de velocidad (ciclos por minuto) , Leída | Input | 16 a 24 | A0
 | int pot |  |  |  | A1
 | bool activa = false; | // Logica (encendida o apagada) , Leída
 | int inhala = true; | // Logica (inhala o exhala) , calculada
 | int pausa = 2000; | // Duracion de la pausa entre mareas en milisegundos, MODIFICABLE
 | int pasosMC = 380; | // Pasos por medio ciclo (depende de mecanismo usado, 200pasos per turn, definida
 | int Tentrepasos = 1 ; | // Tiempo entre pasos para asegurar un numero de ciclos por minuto (Pausa en milisegundos, calculada)
Version 3
 | //Variables médicas modificables en firmware |  |  |  |  |  | Función | Rango | Cambiable vía | Fijada
 | int ciclosmin = 16; // Minimo de ciclos por minuto |  |  |  |  |  | Volumen aire | 175 a 600 cc | Tablero | No
 | int ciclosmax = 25; // Maximo de ciclos por minuto |  |  |  |  |  | Respiraciones por minuto | 16 a 25 RPM | Tablero | No
 | float FInsp = .42; // fracción inspiratoria = Tiempo Inspiracion/Tiempo total ciclo (.42 recomendado) SE PUEDE PONER UN POTENCIOMETRO PARA VARIAR |  |  |  |  |  | Fracción inspiratoria | 0.42 | Firmware | Si
 | int TMeseta = 500 ; // Tiempo de Meseta en milisegundos (Presión alta mantenida antes de pasar a Exhalación) |  |  |  |  |  | Meseta | 500 milisegundos | Firmware | Si
 | int Pausa = 0; // Duracion de la pausa adicional entre mareas en milisegundos, |  |  |  |  |  | Pausa al final marea | 0 | Firmware | Si
 | int presionmax = 40; // Presion maxima en cualquier momento. PARA EL EQUIPO. |  |  |  |  |  | Sensor de presion y temperatura |  | Firmware | Si
 | int presionmin = -5; // Presion minima durante espiracion. Señal advertencia |  |  |  |  |  | Válvula mecánica sobrepresión | 60cmH2O | NO | Si
 | int tempmax = 39; // Temperatura maxima del aire |  |  |  |  |  | Salto de pasos por sobrepresion | 40cmH2O | NO | SI
 | // volumen segun ambu y posicion del reostato |  |  |  |  |  | Conexión a oxigeno | Disponible
 |  |  |  |  |  |  | Alarmas | varias fallas mecánica, presion, etc | Tablero
 |  |  |  |  |  |  | 1= falla de motor/origen, | pasos | Firmware | Si
 |  |  |  |  |  |  | 2= Falla de origen del brazo, | pasos | Firmware | Si
 |  |  |  |  |  |  | 3= Exceso de presion | 40cmH2O | Firmware | Si
 |  |  |  |  |  |  | 4= Presion demasiado baja | -5cmH2O | Firmware | Si
 |  |  |  |  |  |  | 5= Sobre temperatura | 40C | Firmware | Si
 |  |  |  |  |  | 0 | 200 | 15
 |  |  |  |  |  | 1 | 240 | 16
 |  |  |  |  |  | 2 | 280 | 17
 |  |  |  |  |  | 3 | 320 | 18
 |  |  |  |  |  | 4 | 360 | 19
 |  |  |  |  |  | 5 | 400 | 20
 |  |  |  |  |  | 6 | 440 | 21
 |  |  |  |  |  | 7 | 480 | 22
 |  |  |  |  |  | 8 | 520 | 23
 |  |  |  |  |  | 9 | 560 | 24
 |  |  |  |  |  | 10 | 600 | 25

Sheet: Mecanica
 |  |  | Freq max | 25 | 0.72 | ( .3 del total) Duracion Ciclos inpiracion en segundos
 |  |  | Recorrido necesario max |  | 60 | mm
 |  |  | Pasos por vuelta |  | 200
 |  |  | Pi |  | 3.14159
 |  | Diametro mm | Circunferencia | Pasos | RPS | RPM | Vueltas
 | Eje motor | 18 | 56.54862 | 212.20677 | 1.473658125 | 88.41948751 | 1.06103385
 |  | 20 | 62.8318 | 190.986093 | 1.326292313 | 79.57753876 | 0.9549304651
 |  | 10 | 31.4159 | 381.9721861 | 2.652584625 | 159.1550775 | 1.90986093
 |  | 5 | 15.70795 | 763.9443721 | 5.305169251 | 318.310155 | 3.819721861
Frecuencias driver
 |  |  | Max |  |  |  | Pasos max por minuto
 |  | TB6600 | 200khz | 5e-06 | 5 micros entre pasos |  | 12000000
 |  | TB6560 | 15kHz | 6.666666667e-05 | 66 micros entre pasos
 | Chino nuevo (http://toshiba.semicon-storage.com/info/docget.jsp?did=14642&prodName=TB67S109AFTG) | TB67S109 | 100kHz | 1e-05 | 10 micros entre pasos |  | 6000000
 | https://reprap.org/forum/read.php?415,826601 | Real | 20khz |  | 50 micros signal
Presiones |  |  | cm H20 | Bar | Pa | hPa | PSI | ATM standard
 | 5 | 1 cm H2O | 5 | 0.004903325 | 490.32 | 24.52 | 0.071115 | 0.004839053094
 | 1 | 1 Bar | 203.94 | 1 | 100000.00 | 1000.00 | 14.5034237 | 0.9868921791
 | 1 | 1 Pascal | 0.002039488578 | 1e-05 | 1 | 0.01 | 0.000145037738 | 9.869231693e-06
 | 1 | 1 hPascal | 0.04 | 0.001 | 100 | 1 | 0.0145037738 | 0.0009869231693
 | 1 | 1 PSI | 14.06 | 0.07 | 6894.76 | 68.95 | 1 | 0.0680454629
 | 1 | 1 ATM | 206.65 | 1.01 | 101325.01 | 1013.25 | 14.70 | 1
BMP280 |  | Desde | Hasta
 |  | 300 | 1100 | hPa
 |  | 0.3 | 1.1 | bar
Respirador | -5 | 0 | 1 | 30 | cmH20
 | 0.99 | 1.01328192 | 1.02 | 1.16 | bar | 0 es presion atmosferica medida
 | 988.7652929 | 1013.281918 | 1018.185243 | 1160.381668 | hPa
RPM | TCiclo Tiempo ciclo (mili s) | Duracion total respiraciones para un minuto (s) | Tentrepasos calculato menos tiempos adicionales
16 | 3725 | 59.6
18.7 | 3208 | 59.9896
22.2 | 2702 | 59.9844
25 | 2400 | 60
22.3 | 2690 | 59.987 |  | 987.1261853
18.28 | 2690 | 49.1732 | 0.5922757112 | segundos tardan las medidas y actividades colaterales por ciclo
CPM | tiempo del ciclo (millis) | factor inspiratorio | duracion insp (milis) | micros | a 300 pasos/ insp por dos
12 | 5000 | 0.42 | 2100 | 2100000 | 3500

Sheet: Testing
Pruebas en Buehler Pharma 11/06/2020
Técnico: Efren Lopez
Con mascarilla |  | Set | Analizador | Set | Analizador
 | Frecuencia | 20 | 20.81 | 20 | 20.87 | RPM
 | Volumen | 500 | 376 | Max | 612 | ml
 | PEEP | 0 | 0 | 0 | 0 | cmH2O
Con pulmón |  | Los test con pulmón de pruebas no pudieron ser usados, ya que el equipo de calibración esta diseñado para medir y retener el PEEP en una sola dirección (Ventiladores con dos mangueras separadas). Esto hizo que el PEEP se mantuviera a una presión muy elevada (20cmH2O), impidiendo el flujo de renovación.
 |  | Set | Analizador | Set | Analizador
 | Frecuencia | 20 | 20.81 | 20 | 20.63 | RPM
 | Volumen | 500 | 208 | Max | 193 | ml
 | PEEP | 0 | 20 | 0 | 20 | cmH2O

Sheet: Lista materiales
Lista materiales
 | Parte | Especificación | Cantidad | Origen | Precio | Nota
 | Aire
 | Resucitador Ambulatorio AMBU |  | 1 | Nuevo | $35.00 | 1
 | Conectores (como punto instalación de sensores) | Impreso 3D | 2 | Nuevo | $1.00 | 2
 | Manguera extensión | Manguera cableado | 1m | Construcción | $1.00 | 3
 | Electronica
 | Fuente de poder | ATX-PSU de PC (https://en.wikipedia.org/wiki/Power_supply_unit_(computer)) | 1 | Reciclado | $0.00 | 4
 | Motor NEMA23 | 2.4 A, 13.9Kg.cm (1.36Nm) (https://www.ebay.com/itm/New-Nema-23-Stepper-motor-Sanyo-Denki-142-ozin-CNC-ROUTER-MILL-LATHE-ROBOT-0666/121701679248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) | 1 | Reciclado | $0.00 | 5
 | Arduino Nano | Nano (https://www.ebay.com/itm/Mini-USB-Nano-V3-0-ATmega328P-5V-16M-Micro-Controller-Board-for-Arduino/174120707751) | 1 | Nuevo | $3.12 | 6
 | Driver Motor | 5 Amp TB6600 (https://www.ebay.com/itm/CNC-Single-Axis-TB6600-0-2-5A-Two-Phase-Hybrid-Stepper-Motor-Driver-Controlle/254581090595) | 1 | Nuevo | $8.00 | 7
 | Switch encendido |  | 2 | Reciclado | $2.00
 | Rheostato | 10kΩ | 2 | Reciclado | $0.00 | controles
 | Sensor óptico |  | 1 | Reciclado | $0.00 | motor
 | Zumbador |  | 1 | Reciclado | $0.00
 | Switch mecánico |  | 1 | Reciclado | $0.00 | cierre
 | Sensor Presión y temp | BMP280 | 1 |  | $4.00
 | Resistencias | 5kΩ | 2
 |  | 470Ω | 1
 | Led | Rojo | 1 | Reciclado |  | Falla
 |  | Verde | 1 | Reciclado |  | Operando
 | Caja con mecanismo | Acrílico 5mm | 1 | Corte Laser | $52.00 | 8
 | Tornillos M3 con tuerca | 15mm | 52 |  | $5.00
 |  | 20mm | 4 |  |  | Brazo
 |  | 50 mm | 2 |  |  | Mecanismo
 |  | 10 mm (autoroscante) | 3 |  |  | Seguros
 | Tornillos M4 con tuerca | 50mm | 1 |  |  | Eje
 |  | 10 mm | 4 |  |  | Fuente
 | Tornillos M5 con tuerca | 20mm | 4 |  |  | Motor
 | Manija | 4 pulgadas entre centros | 1 |  | $1.00
 | Hules base | min 3mm espesor | 4 | Reciclado | $0.00 | pegados
 | Varios
 | Cuerda trenzada pesca | 2 a 3mm | 30cm |  | $0.00 | Mecanismo
 | Cinta adhesiva ancha |  | 20cm |  | $0.00 | Bisagra
 | Cianoacrilato |  |  |  | $2.00
 | Cinta electrica o tubo cableado |  |  |  | $2.00
 |  |  |  | Costo total | $116.12
 | En fase siguiente, con pantalla
 | Pantalla
 | Arduino nano mas interfase I2C o Arduino grande (UNO o Mega)
 | Sensores
 | Humedad, temperatura y presión | BMP280 (https://www.ebay.com/itm/5pcs-BMP280-Pressure-Sensor-Arduino-High-Precision-Atmospheric-sensor-USA/133096057311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) |  |  | $2.00 | que pueda medir presión de 0 a 50cmH2O, o hasta negativa
 | Humedad y temperatura | DHT22 (https://www.ebay.com/itm/DHT22-AM2302-Digital-Temperature-and-Humidity-Sensor-Replace-SHT10-SHT11-SHT15/201234462574) |  |  | $4.00
 | Biomonitor | Pulso
 |  | Oxigenación
 |  | Temperatura

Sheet: Equipos producidos
Equipos producidos
 |  |  |  |  |  |  |  | AMBU 1 |  |  | AMBU 2
 | Numero | Modelo | AMBU | De | Notas | Historia
 | 0 | 0 | 0 | Restos | Versiones previas con sistemas mecanicos varios
 | 1 |  | 1 | Daniel
 | 2 |  | 1 | Ramiro
 | 3 |  | 1 | Aram
 | 4 | 1.3 | 1 | Heidi | Covid CHI
 | 5 | 1.4 | 2 |  | Lamina de 4mm
 | 6 | 1.5 | 2 |  | 8ruedas, bracito 3 en desde ruedas (AMBU queda deformado)
 | 7 | 8 | 2 |  | 2 soportes laterales internos , MOTOR SUPER SILENCIOSA, ruidosa de borde ambu | Schottky USB quemado,no 5v
 |  |  |  |  |  | Añadir soporte adicional ambu
 | 8 | 2 | 2 |  | 8 ruedas
 | 9 | 2 | 2 |  | 8 ruedas
 | 10 | 2 | 2 |  | 8 ruedas
 | 11
 | 12
 | 13
 | 14
 | 15
 |  |  |  |  |  | Accion posible | Verificaciones control de calidad: |  |  | Valor
 |  |  |  |  |  |  |  | Serie de pruebas CC | Equipo 5 | Equipo 6 | Equipo 7 | Equipo 8
 | Driver a 3A |  |  |  |  |  | Previos
 |  |  |  |  |  |  |  | Mecanismo | 1.4 | 1.5 | 1.5 | 1.5
 |  |  |  |  |  | Instalar |  | Firmware instalado | RespiraDQ3Dv09 | RespiraDQ3Dv09 | RespiraDQ3Dv09 | Ver20 Debug
Historial equipos |  |  |  |  |  |  |  | Modificaciones firmware | NO | NO | NO | NO
 | 3 | Entregado a Aram, no news |  |  |  |  |  | Microstep |  | 2 | 1
 | 4 |  | Entregado Heidi |  |  |  |  | Numero de ruedas | 4 | 8 | 8
 |  | 2020-07-22 | Lester tecnico Chi |  |  | bracito 1=cortito 4= largote |  | Longitud bracito | 2 | 3 | 3
 |  |  | Lo probaron como ventilador, no funciono |  |  |  | Preflight
 |  |  | usaron pulmon no compliant y no lo pudo inflar |  |  |  | 1.1 | Serial OK | OK | OK | OK | OK
 |  |  | No dio el volumen reportado |  |  | Revisar switch | 1.2 | LED Puerta y encendido | OK | OK | OK | OK
 |  |  | No tenia el ritmo RPM indicado |  |  | Lineas a BMP | 1.3 | Sensor BMP280 | OK | OK | OK | OK
 |  |  | Recomienda uso ambulatorio (traslados a managua) |  |  | Lubricar brasos, ubicar bien origen motor | 1.4 | Retorno a origen inicial | OK | OK | OK | OK
 |  |  | Mas fuerza al motor ( el ambu muy duro…) |  |  | Parlante pin D13 | 1.5 | Inicio: Pitidos ok | OK | OK | OK | OK
 |  |  | Alarma no se apagaba (no usaron reset)
 |  |  | Intensivistas ni lo vieron |  |  |  | Operación basica
 |  |  |  |  |  |  | 1.6 | Motor mueve contra el reloj | OK | OK | OK | OK
 |  | 2020-09-01 | Terminado equipo dual Eq08 |  |  |  | 1.7 | Brazos regresan a origen | OK | OK | OK | OK
 |  | 2020-09-05 | Haciendo modificaciones equipo 5 para dual con placa base escudo |  |  |  | 1.8 | Rheostato RPM | OK | OK | OK | NO
 |  |  |  |  |  |  | 1.9 | Rheostato Volumen | OK | OK | OK | NO
 |  |  |  |  |  |  | Prueba operativa equipo
 |  |  |  |  |  |  | 2.1 | Volumen minimo @20RPM |  | 80 a 150 | 150 |  | sin pulmon
 |  |  |  |  |  |  | 2.2 | Volumen medio @20RPM |  | 250a300 | 360a400
 |  |  |  |  |  |  | 2.3 | Volumen maximo |  | 520a600 | 560a600
 |  |  |  |  |  |  | 2.4 | RPM min |  | 16 | 16
 |  |  |  |  |  |  | 2.5 | RPM max |  | 25 a 28 | 30 a 31 |  |  | VentMon
 |  |  |  |  |  |  | 2.6 | Alarma por presion |  | ok | ok
 |  |  |  |  |  |  | 2.7 | Alarma por otro |  | ok | ok
 |  |  |  |  |  |  | 2.8 | Reset alarma |  | ok | ok
 |  |  |  |  |  |  | 2.9 | Retorno a origen sobre la marcha |  | ok | ok
 |  |  |  |  |  |  | 3 | Posicion brazos |  | ok | ok
 |  |  |  |  |  |  | 3.1 | Mecate tilinte despues de 2 horas |  | ok | ok

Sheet: Ciclo COVID
Ciclo covid
 | Inicio (Día) | Promedio | Max (Día) | Final (Día)
Infección | 1 | 1 | 1 | 1
Incubación | 2 | 5.2 | 12 | 21 | Vias respiratorias superiores | https://www.nejm.org/doi/full/10.1056/NEJMoa2001316
Capacidad contagio
Síntomas
Agravamiento (Desde inicio sintomas) | 4 |  | 10 | despues 14 |  | https://pubs.rsna.org/doi/full/10.1148/radiol.2020200370
Curación
 |  |  |  |  |  | https://www.sciencedirect.com/science/article/pii/S0896841120300469

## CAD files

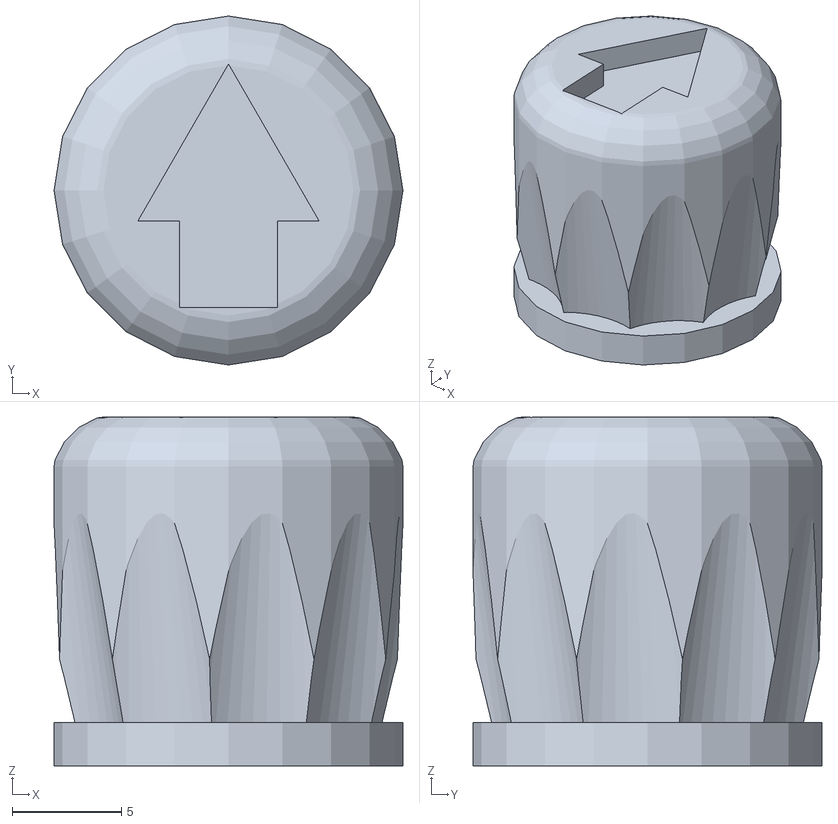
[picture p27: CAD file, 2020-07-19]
00 Diseño/Impreso 3D/potknob_parametric sin tornillo.stl
16.0 x 16.0 x 16.0

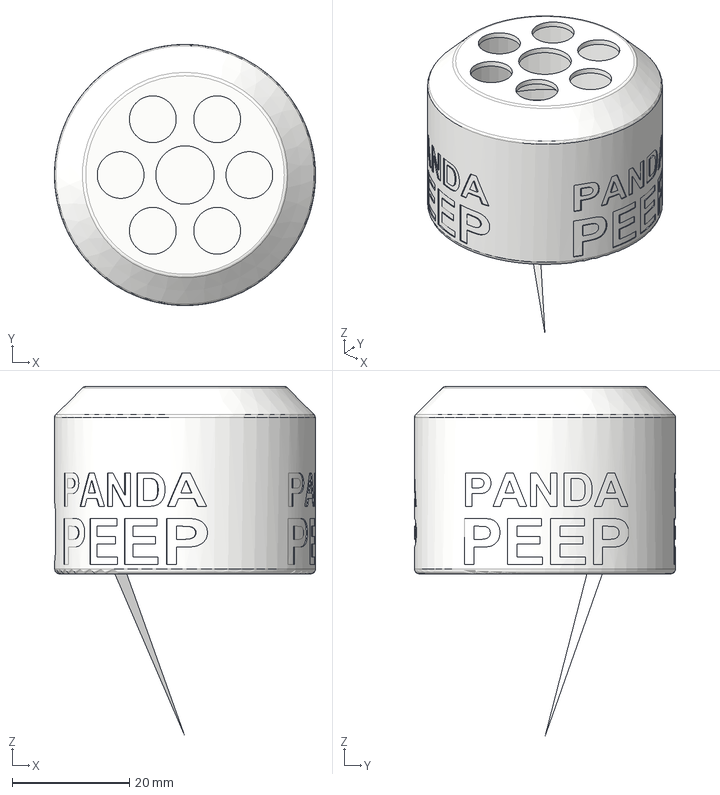
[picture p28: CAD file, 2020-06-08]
03 Accesorios, valvulas, sensores/peep/PANDApeep+Gen2+PEEP+valve/files/cover_gen2.step
44.6 x 44.6 x 59.8 mm

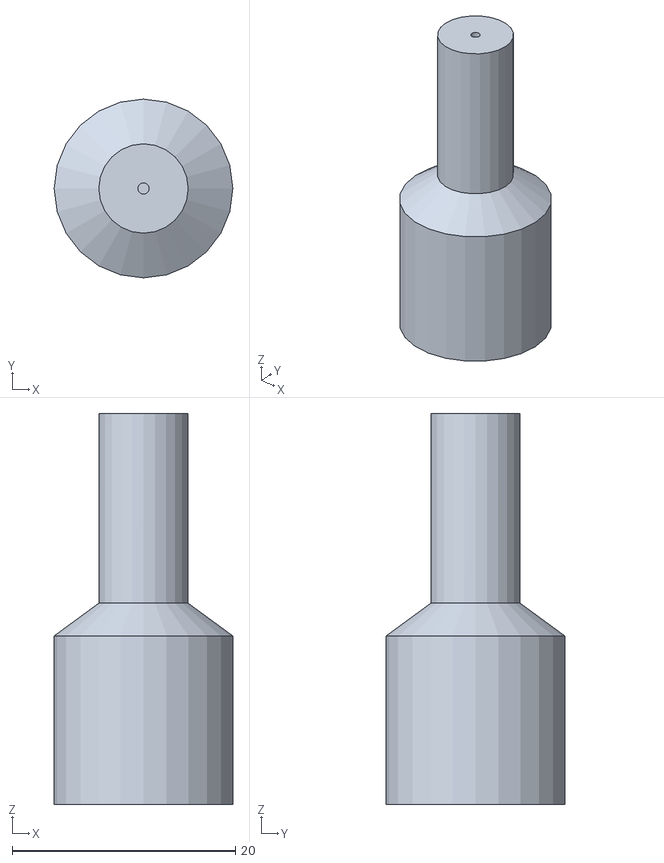
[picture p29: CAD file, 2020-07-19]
00 Diseño/Impreso 3D/Jalador 8mm para eje 6mm ver2.stl
16.0 x 16.0 x 35.0

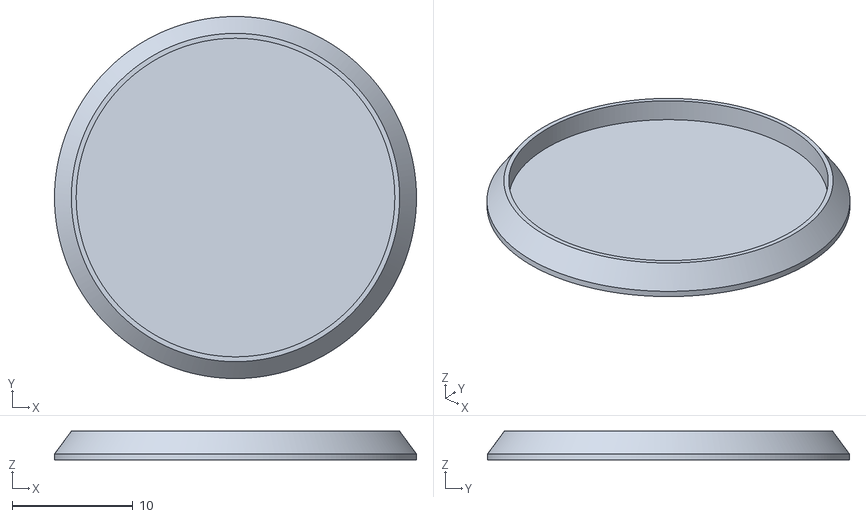
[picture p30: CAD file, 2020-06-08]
03 Accesorios, valvulas, sensores/peep/PANDApeep+Gen2+PEEP+valve/files/TPU_seal.stl
30.0 x 30.0 x 2.40

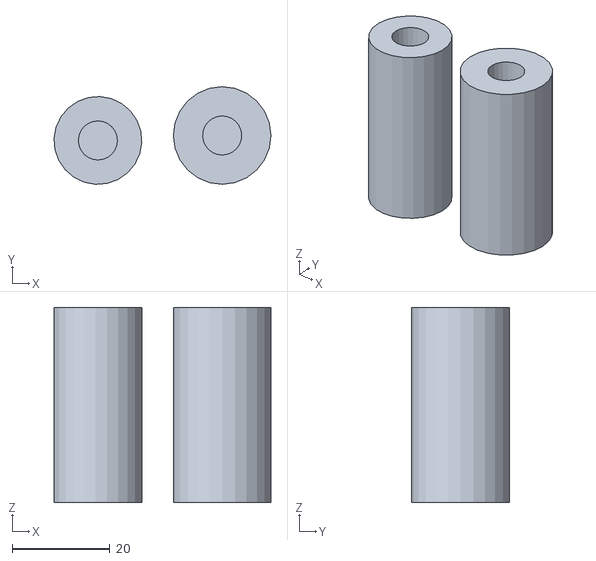
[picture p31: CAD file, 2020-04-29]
00 Diseño/Impreso 3D/Respirador AMBU DQ3D 18 y 20mm.stl
44.4 x 20.0 x 40.0

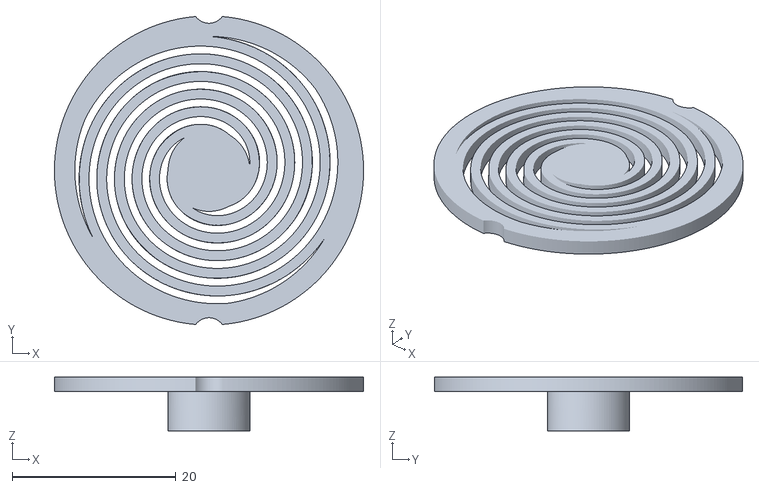
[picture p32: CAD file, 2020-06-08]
03 Accesorios, valvulas, sensores/peep/PANDApeep+Gen2+PEEP+valve/files/flatspring_gen2_inline.stl
37.8 x 37.7 x 6.60

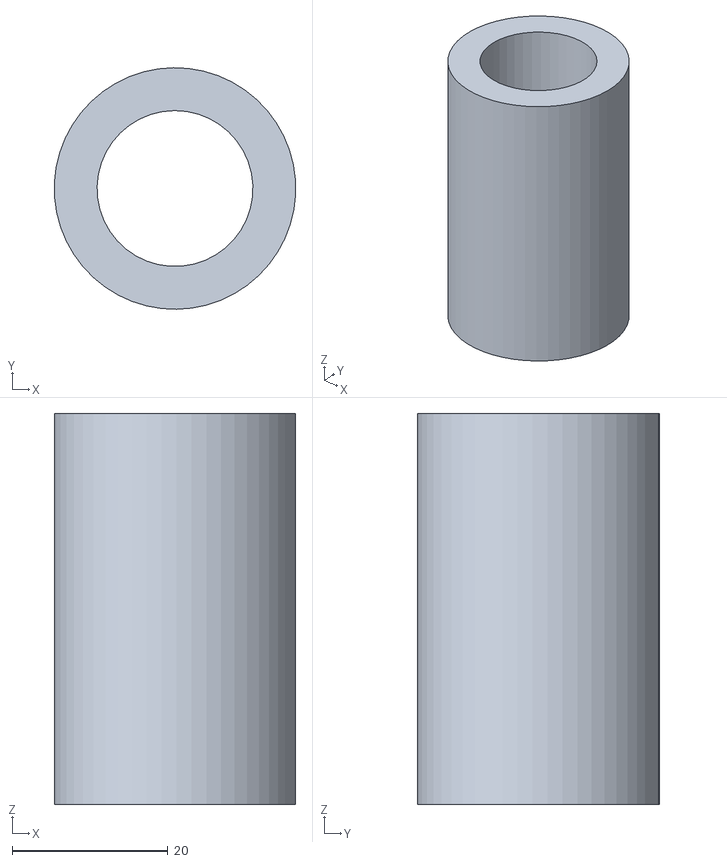
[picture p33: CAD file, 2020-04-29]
00 Diseño/Impreso 3D/Adaptador 25 a 22 manguera mascara v2.stl
31.0 x 31.0 x 50.2

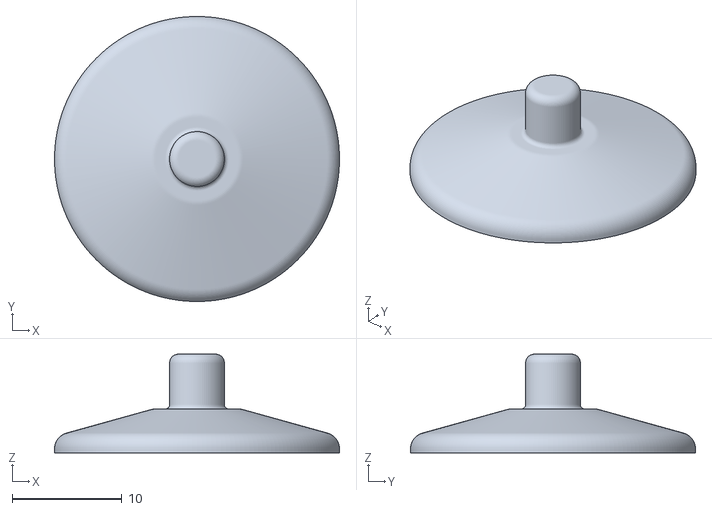
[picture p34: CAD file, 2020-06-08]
03 Accesorios, valvulas, sensores/peep/PANDApeep+Gen2+PEEP+valve/files/disc_gen2.stl
26.0 x 26.0 x 9.00

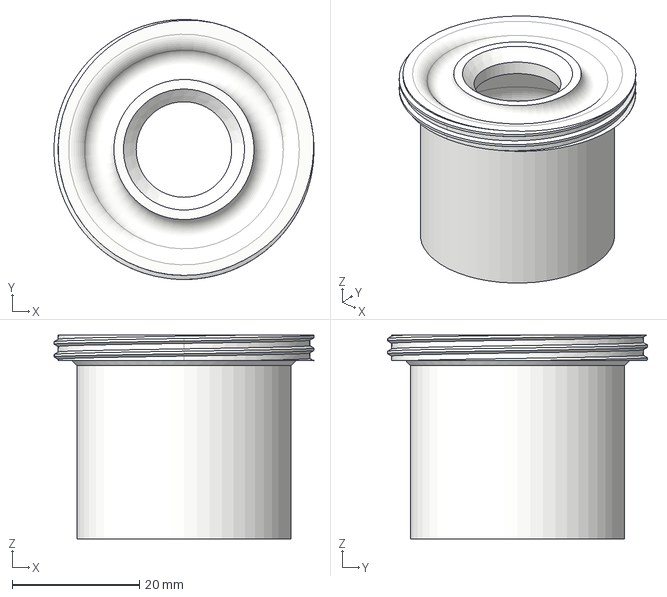
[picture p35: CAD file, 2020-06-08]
03 Accesorios, valvulas, sensores/peep/PANDApeep+Gen2+PEEP+valve/files/base_gen2.step
40.8 x 40.8 x 32.0 mm

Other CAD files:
00 Diseño/Respirador AMBU DQ3D v1.1 solo.skp
03 Accesorios, valvulas, sensores/peep/PANDApeep+Gen2+PEEP+valve/files/base_gen2.stl
03 Accesorios, valvulas, sensores/peep/PANDApeep+Gen2+PEEP+valve/files/cover_gen2.stl

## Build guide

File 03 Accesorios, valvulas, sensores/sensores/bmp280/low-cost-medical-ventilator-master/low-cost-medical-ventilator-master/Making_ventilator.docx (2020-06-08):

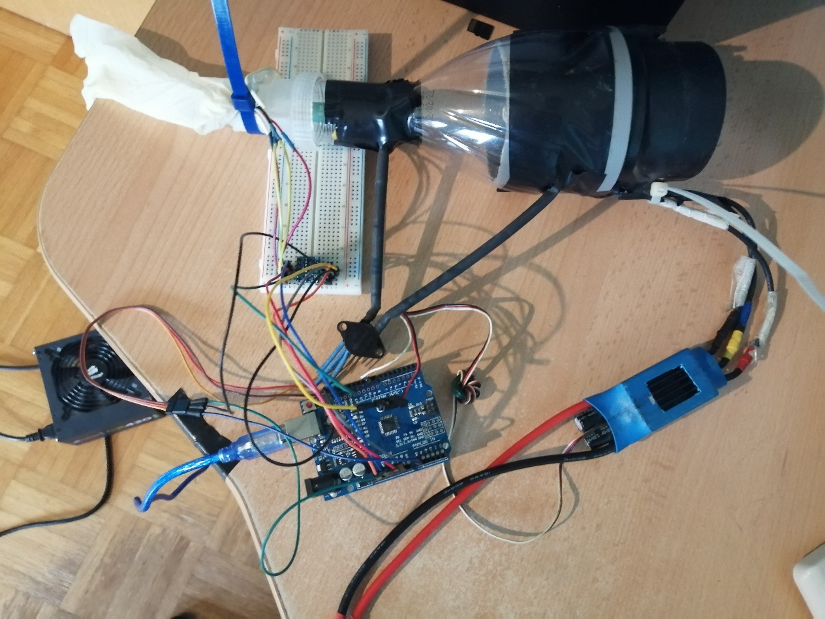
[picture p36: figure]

Arduino and ESC – connect ESC black to arduino GND. Connect ESC white to arduino DigitalPWM 9.

MPX5010DP – (search »MPX5010DP datasheet« on google). Connect pin on the right (on the pic) to arduino 5V. Middle pin goes to arduino GND. Pin on edge is signal and goes to arduino ANALOG IN A0 pin.

BMP280 – is a 3.3V module, so you need a 3.3 – 5V converter. Check datasheet, make sure to connect all BMP280 pins to LOW-VOLTAGE part of 3.3-5 converter. Also connect Arduino 3.3 and GND to LOW-VOLTAGE PART of 3.3-5v converter.

Connect arduino 5V and GND to HIGH-VOLTAGE part of converter. Connect the high-voltage signals to arduino SCK and SDA pins.

Converting pressure difference to flow:

https://en.wikipedia.org/wiki/Venturi_effect

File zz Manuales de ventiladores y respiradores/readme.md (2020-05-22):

Links anotados
A Guide To Designing Low-Cost Ventilators for COVID-19
https://www.youtube.com/watch?v=7vLPefHYWpY

The basics of respiratory mechanics: ventilator-derived parameters
https://www.ncbi.nlm.nih.gov/pmc/articles/PMC6212352/

Manuales de equipos comerciales

NIPPY3+
http://www.nippyventilator.com/wp-content/uploads/woocommerce_uploads/2017/11/NIPPY-3-IFU-Nov-2017.pdf

Newport
http://www.frankshospitalworkshop.com/equipment/documents/ventilators/service_manuals/Newport_e360_Ventilator_-_Service_manual.pdf

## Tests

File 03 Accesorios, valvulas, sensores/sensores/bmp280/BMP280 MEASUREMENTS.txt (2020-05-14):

Ahmed Nasr I want to understand something, it's required to measure (0 to 40 cmH2O), BMP280 measures pressure in range of (300 to 1100 hPa) which is multiplications of required pressure to be measured, how could you measure the pressure by this sensor ?

am I misunderstanding something ?

    Boris Kuster
    Boris Kuster The 0-40 cmH2O refers to relative pressure. (Relative in regards to atmospheric pressure). So, 40cm H20 means 0.04 bar. So absolute pressure in patient lungs that must be measured is 1bar - 1.04 bar. BMP280 measures (300 to 1100 hPa) which is 0.3 to 1.1 bar.

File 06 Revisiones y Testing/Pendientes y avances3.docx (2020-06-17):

Pendientes y avances del 22 de mayo al 17 de Junio

1. Presión
- Organizar todos los elementos de presión en un archivo (columna video, Graficas, etc)
- Regular válvula mecánica a 30cmH2O ( Teflón y 2 vueltas menos)
- Se instaló una válvula PEEP impresa con un adaptador para el AMBU
- Si paciente espira durante inspiración (aumento de presión mayor al esperado) motor suspende medio ciclo para sincronizarse con paciente. Igual en lo inverso
2. Volumen
- Aprobada donación válvula intermedia sensores de Robert Reed (USA)
3. Mecánica (firmware)
- Mejorar retornos a origen iniciales y sobre la marcha
- Programar interrupt para suspender alarmas
- Medidas de presión (2 sensores) cada 100 milisegundos
- Construir maquinas 3 y 4
4. Pruebas
- Hecha prueba con pulmón artificial BuhlerFarma (Lunes 8 de Junio) https://www.youtube.com/watch?v=ZXE7Wcpd6EI

Medidas presión cada 100 milisegundos

USAR BMP en Normal mode, cada 100ms

Alarma cada 500 milisegundos, numero pitidos según alarma, luego pausa de 1 segundo

Main changes from May 22 to June 14:

The machine was tested by the local Ventilator provider (BuehlerPharma) and passed the basic tests https://www.youtube.com/watch?v=ZXE7Wcpd6EI .

A series of improvements in the management of pressure are described here (https://github.com/DQUEROL/Respirador-DQ3D-NICA/blob/master/06%20Revisiones%20y%20Testing/Factores%20relacionados%20con%20la%20presi%C3%B3n%20Respirador%20DQ3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) , including PEEP and firmware pressure management.

Firmware was modified to continue operation even while certain warning alarm are triggered, and can be reset on the fly. Also, every cycle the machine checks its status, and recalibrates if needed.

4 machines have been built until now, and I have been looking for 7,000US in order to build 10 more and cover the prior expenses, but to no avail. I am waiting for Robert Reed´s sensor.

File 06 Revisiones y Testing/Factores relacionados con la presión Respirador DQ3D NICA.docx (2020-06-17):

# Respirador DQ3D NICA

# Factores relacionados con la presión

29 05 2020

## 1. Medición de presión

### Columna de agua

Método de referencia, sencillo de fabricar, pero

difícil de usar en ambiente hospitalario.

https://youtu.be/ov6TxPRoqqE

### BMP280

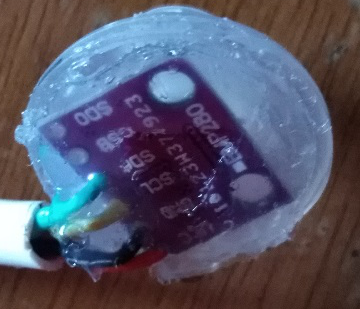
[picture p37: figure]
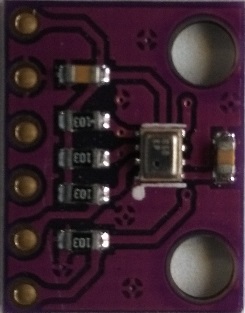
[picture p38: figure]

Sensor pequeño y económico que mide presión y temperatura. Podrá ser reemplazado por BME 280 que también mide humedad.

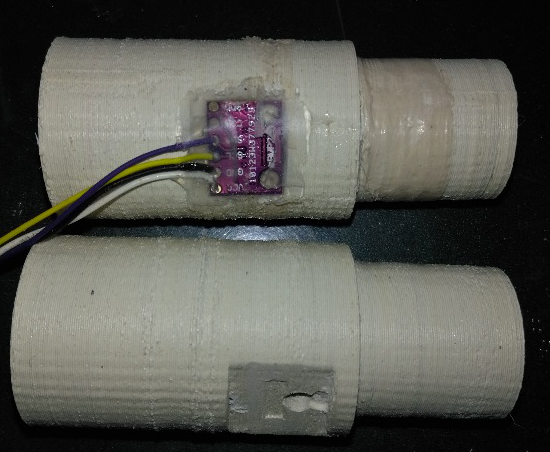
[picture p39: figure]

Conectado vía I2C para poder utilizar varios sensores simultáneamente, sin ocupar mas pines del Arduino Nano.

### Graficas

Actualmente lee 10 datos y saca el promedio hacia la grafica

Mejora: Mide cada 100millis

## 2. Manejo de Presión máxima

La válvula de seguridad por alta presión (con resorte) está ubicada al final de la manguera y únicamente evita presiones catastróficas 40-60 cmH2O. Se redujo presión con dos vueltas menos y teflón para fijar, a approx. 30cmH2O

Por ello se incluyó además una medida de los sensores en el firmware que suspende el funcionamiento de la maquina a presiones superiores a 30 cmH2O. (modificable)

A altas velocidades de CPM, el sistema AMBU genera mayores presiones, pero por razones mecánicas, el sistema se autoregula (salta pasos) cuando las presiones rebasan los 25 cmH2O.

## 3. Manejo de Presión mínima

Se incluyó una medida de los sensores en el firmware que suspende el funcionamiento de la maquina a presiones inferiores a -5 cmH2O. (modificable)

## 4. PEEP

El AMBU utilizado tiene una válvula de diafragma justo antes de la mascarilla que deja salir el aire espirado por un conjunto de orificios (directamente al ambiente!!).

Mejora: Se instaló una válvula PEEP impresa con un adaptador para el AMBU


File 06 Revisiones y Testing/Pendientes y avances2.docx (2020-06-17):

Pendientes y avances del 22 de mayo al 5 de Junio

1. Presión
- Organizar todos los elementos de presión en un archivo (columna video, Graficas, etc)
- Regular válvula mecánica a 30cmH2O ( Teflón y 2 vueltas menos)
- Se instaló una válvula PEEP impresa con un adaptador para el AMBU
- Si paciente espira durante inspiración (aumento de presión mayor al esperado) motor suspende medio ciclo para sincronizarse con paciente. Igual en lo inverso
2. Volumen
- Aprobada donación válvula intermedia sensores de Robert Reed (USA)
3. Mecánica
- Mejorar retornos a origen iniciales y sobre la marcha
- Programar interrupt para suspender alarmas
- Medidas de presión (2 sensores) cada 100 milisegundos
- Construir maquinas 3 y 4
4. Pruebas
- prueba con pulmón artificial BuhlerFarma (Lunes 8 de Junio)
5. Financiamiento
- Carta a Rafael Henríquez
6. Publicar github. Actualizar tabla valores médicos y testing

Ideas interrupt o millis()

Usar millis siempre que quieras, interrupts solo cuando indispensable

Demonstration code for several things at the same time

https://forum.arduino.cc/index.php?topic=223286.0

https://forum.arduino.cc/index.php?topic=503368.0

Opcion multiple https://www.instructables.com/id/Non-blocking-Virtual-Delay-Library-for-the-Arduino/

Ultima instancia https://code.google.com/archive/p/rogue-code/wikis/ToneLibraryDocumentation.wiki

Medidas presion cada 100 milisegundos

USAR BMP en Normal mode, cada 100ms

Ver tabla 15, elevator

single burst read

Alarma cada 500 milisegundos, numero pitidos segun alarma, luego pausa de 1 segundo

Interrupts

https://www.instructables.com/id/Arduino-Timer-Interrupts/

Hay dos interrupt pins para input, pero los interrupt pueden trabajar sin pin.

Configurar tiempos de muestreo

compare match register = [ 16,000,000Hz/ (prescaler * desired interrupt frequency) ] - 1

remember that when you use timers 0 and 2 this number must be less than 256, and less than 65536 for timer1

One last thing to note- certain timer setups will actually disable some of the Arduino library functions. Timer0 is used by the functions millis() and delay(), if you manually set up timer0, these functions will not work correctly.

Additionally, all three timers underwrite the function analogWrite(). Manually setting up a timer will stop analogWrite() from working.

you can't use millis() to create a delay IN AN ISR. And, you can't use delay() IN AN ISR.

https://circuitdigest.com/microcontroller-projects/arduino-interrupt-tutorial-with-examples

https://aprendiendoarduino.wordpress.com/tag/isr/

Placa int.0 int.1 int.2 int.3 int.4 int.5

Nano, Uno, Ethernet 2 3

https://www.arduino.cc/reference/en/language/functions/external-interrupts/attachinterrupt/

arduino I2C interrupt

https://arduino.stackexchange.com/questions/9388/reading-i2c-sensors-with-a-timer-interrupt

http://www.gammon.com.au/i2c

Where is my I2C address (http://blascarr.com/i2c-address/)

SPI interrupts

https://www.arduino.cc/en/Reference/SPIusingInterrupt

https://www.arduino.cc/en/Tutorial/DigitalPotControl

https://www.allaboutcircuits.com/technical-articles/using-interrupts-on-arduino/

| method | resolution | max. time | typ. overhead |

| `millis()` | 1 – 2 ms | 49.7 days | 0.69 – 1.3 µs |

| `micros()` | 4 µs | 71.6 min | 2.8 – 2.9 µs |

| Timer 1 | 0.0625 µs | 4.096 ms | 0.25 – 0.5 µs |

| pin toggling | scope-limited | ∞ | 0.125 µs |

| cycle counting | 0.0625 µs | boredom-limited | 0 |

| looping | N.A. | N.A. | 0.25 µs |

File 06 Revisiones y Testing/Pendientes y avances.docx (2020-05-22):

Pendientes y avances al 22 de mayo

1. Retorno a punto origen RESUELTO
- Inicial

Oscilar 10,20,30, a 80 pasos para encontrar optoMotor == 1

- En marcha

Solo puede perder pasos por sobre fuerza durante inspiración

ergo

si optoBrazo u optoMotor ==0 (no están en origen) , INSPIRAR hasta que ambos en origen.

2. Presión
- Reportar presión mínima y máxima de cada medio ciclo RESUELTO
- El motor salta pasos si la presión es mayor a 37cmH2O, RESUELTO
- Regular válvula mecánica a 40 ( resorte menos fuerte)
- Checar porque hay 1cm de diferencia entre BMP y columna de agua, filmar correspondencias. RESUELTO
- PENDIENTE Si paciente espira durante inspiración (aumento de presión mayor al esperado) motor suspende medio ciclo para sincronizarse con paciente

https://www.best-microcontroller-projects.com/bmp280.html

https://github.com/orgua/iLib/blob/master/src/i2c_BMP280.h

3. Volumen
- Medir volúmenes según pasos, pichel agua, hacer tabla conversión,
- determinar aumento de rueditas de presión, más volumen
4. Mecánica,
- talvez aumentar tamaño eje (menos vueltas, menos pasos, más fuerza a altas velocidades de bombeo, menos ruido con microstepping?
- Conector intermedio 22mm .STL rediseñar sencillo y poner punto de fijación BMP280
5. Publicar github. Actualizar tabla valores médicos y testing

Visualizar datos en PC

https://asksensors.com/

https://github.com/asksensors/AskSensors-ESP8266-DHT

https://www.mathworks.com/matlabcentral/fileexchange/25519-collect-and-plot-data-from-an-instrument-in-real-time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

https://visualstudio.microsoft.com/es/

https://create.arduino.cc/projecthub/whitebank/arduino-heating-element-control-224882

Interrupts

https://circuitdigest.com/microcontroller-projects/arduino-interrupt-tutorial-with-examples

https://aprendiendoarduino.wordpress.com/tag/isr/

Placa int.0 int.1 int.2 int.3 int.4 int.5

Nano, Uno, Ethernet 2 3

arduino I2C interrupt

https://arduino.stackexchange.com/questions/9388/reading-i2c-sensors-with-a-timer-interrupt

http://www.gammon.com.au/i2c

Where is my I2C address (http://blascarr.com/i2c-address/)

SPI

https://www.arduino.cc/en/Reference/SPIusingInterrupt

https://www.arduino.cc/en/Tutorial/DigitalPotControl

https://www.allaboutcircuits.com/technical-articles/using-interrupts-on-arduino/

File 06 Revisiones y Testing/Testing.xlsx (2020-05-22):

Las pruebas 1 a 4 se realizaron con el equipo operando durante 8 dias continuos, a 24 Respiraciones por minuto, con el volumen máximo, sin mascarilla
1. Prueba de confianza mecanica
 | Prueba | Fecha inicio | Tipo de tractor | Tiempo prueba (h) | Tiempo entre fallas (h) | Falla | Correccion
 | 1 | 2020-04-18 | Nylon multifilar entorchado .6mm | 2 | 2 | Nylon revienta | Se intento varias veces
 | 2 | 2020-04-27 | Cable acero .5mm | 6 | 6 | Corte cable | Cable mas grueso
 | 3 | 2020-04-30 | Cable acero .8mm | 7.5 | 7.5 | cable con fallas | cambio material
 | 4 | 2020-05-02 | Nylon solido .8mm | 2 | 2 | Eje quebrado, | Eje impreso con 100% de relleno
 | 5 | 2020-05-02 | Nylon solido .8mm | 3 | 3 | Nylon Roto
 | 6 | 2020-05-03 | Nylon solido .8mm | 3 | 3 | Nylon Roto | cambio material
 | 7 | 2020-05-08 | Nylon trenzado 1.2mm | 192 | NA | NINGUNA | NA
2. Prueba recuperación
 | Durante la prueba 7 anterior hubo 4 apagones de varios minutos. El equipo reinició adecuadamentre en cuanto regresó la electricidad.
3. Desgaste de piezas
 | No se detectó desgaste o debilitamiento de piezas despues de los 7 dias de operación continua.
 | El AMBU sufrio un minimo desgaste en el borde de material rigido, y una deformacion de menos de 5mm en su circunferencia
4. Recalentamiento
 | El motor nunca pasó de 40C (con temperatura ambiente hasta 35C). El Driver no se calentó.
5. Prueba volumenes
 | Pasos | Volumen1 | Volumen2
 | 300 | 175 | 175
 | 400 | 200 | 250
 | 500 | 400 | 390
 | 550 | 575 | 600
6. Prueba presiones
 | 1 Las presiones de operación normales ( sin paciente en la mascara) no rebasaron los 20 cmH2O
 | 2. La valvula de seguridad mecánica esta a 60cmH2O o mas, con gran riesgo para los pacientes.
 | 3. El motor no rebasa los 39cmH2O, y empieza a saltar pasos
 | Se verificó el funcionamiento del sensor BMP280, que reporta las presiones hasta 1000 veces por cada ciclo respiratorio, con una precision de 0.05cmH2O.

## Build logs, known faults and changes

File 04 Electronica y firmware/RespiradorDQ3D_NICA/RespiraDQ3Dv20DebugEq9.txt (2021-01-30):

/* Control de respirador DQ3D NICA
 * Mayo 2020
 * 
 * Arduino Nano 
 * Motor Nema23
 * DQ3D.org

Ver 09
Sin MicroStep
min max PasosInsp =150 a 270
presionmin = -800P;  -8cmH2O
cambios calculo tentrepasos y pausita

Ver20
******************************************************************************************
*Recordar cambios de pines  y recorte de mecate o pasos totales para equipos reconstruidos
******************************************************************************************
*2 sensores 
*  BMP280 0x76 distal   Sensor 2  BME1
*y BME280 0x77 proximal Sensor 1  BME2
*
*74HC595 para multiplicar pines de led, 1 por tipo de alarma
  595 pin 14 es Serial data  input(DS o SER), 
  595 pin 12 es latch (Latch Clock(ST_CP o RCLK), 
  595 pin 11 es clock (Shift clock(SH_CP o SRCLK)
  Enciende led x  si data es 2 a la potencia x . Si led x y led y, se suman las potencias
  o sino    bitWrite(data, desiredBit, desiredState) o bitSet(data, desiredBit)lo pone en 1;
*Opcion de respiraciones por minuto o reaccionar a intento respiratorio
 
*Pendientes
    Pulir TODOMAL, lucecitas 
    YA CAMBIO DE PIN 11 y pin 9 porque interfiere con TONE
    YA Cambiar libreria para BMEEEEE280 
    Medir humedad BME280, alarmas y variables
    YA sistema de chequeo de integridad de sensores sobre la marcha 
    YA Reducir uso de serial cuando no hay computadora (version autonoma)
*/
//DEBUGGING******************************************
//#define DEBUG
 
#ifdef DEBUG
 #define DEBUG_PRINT(x)     Serial.print (x)
 #define DEBUG_PRINTDEC(x)     Serial.print (x, DEC)
 #define DEBUG_PRINTln(x)  Serial.println (x)
#else
 #define DEBUG_PRINT(x)
 #define DEBUG_PRINTDEC(x)
 #define DEBUG_PRINTln(x)
#endif 

// No enviar mensajes a pantalla (Uso sin computadora)
//#define SISERIAL

#ifdef SISERIAL
 #define SISERIAL_PRINT(x)     Serial.print (x)
 #define SISERIAL_PRINTDEC(x)     Serial.print (x, DEC)
 #define SISERIAL_PRINTln(x)  Serial.println (x)
#else
 #define SISERIAL_PRINT(x)
 #define SISERIAL_PRINTDEC(x)
 #define SISERIAL_PRINTln(x)
#endif 

//incluir librerias necesarias para sensores
#include <BME280I2C.h>
#include <Wire.h>

#define SERIAL_BAUD 115200
 
//Variables médicas modificables en firmware
#define ciclosmin 16     // Minimo de ciclos por minuto
#define ciclosmax 25     // Maximo de ciclos por minuto
const float FInsp = .5; // fracción inspiratoria = Tiempo Inspiracion/Tiempo total ciclo (.42 recomendado) SE PUEDE PONER UN POTENCIOMETRO PARA VARIAR
const float TMeseta = 0;      // Tiempo de Meseta en milisegundos (Max500)(Presión alta mantenida antes de pasar a Exhalación)

float presionmax = 2942; // Presion maxima en cualquier momento en Pascal. 30cmH2O     PARA EL EQUIPO.
float presionmin = -800; // Presion minima durante espiracion en Pascal. -5cmH2O = -490      Señal advertencia  v09Eq07 -10
#define tempmax 39       // Temperatura maxima del aire
                         // volumen segun ambu y posicion del reostato

//Variables medicas derivadas
float CPM = ciclosmin;    // Ciclos por minuto inicio
unsigned long TCiclo = 60000L/CPM;    // duración del ciclo respiratorio (en milisegundos)
unsigned long Tinicio = millis();     // Marca tiempo de inicio de la respiración
unsigned long pausita = 0 ;               // pausita adicional para ajustar CPM

//Definición pines Digitales y Análogos // XXX Color alambre
#define ResetAlarmaPin 2   // Roj (Interrupt) Boton reset alarma
#define cierrePin 3        //     (Interrupt) Pin libre
#define origenMotPin 4     // Ama Pin de sensor optico para confirmar si Motor regresó a origen. No se han saltado pasos (motor en posicion adecuada) despues de un ciclo
#define direccionPin 5     // Ama Pin direccion Motor 
#define pasosPin 6         // Pur Pin step pasos Motor
#define botonPin 7         // Bla Pin pulsador  (encendido ciclo) y seleccion de tipo de ciclo a partir de version 20 (RPM o Disparo)
#define enablePin 8        // Gri Pin activa y desactiva motor Motor (Verificar con el driver. Driver HY-DIV268N 6600 activa motor con LOW.
#define origenBraPin 11    // Ama Pin (endstop) para confirmar brazo en punto de partida  ERA PIN 9 ahora en 11
#define dataPin 10         // Ama 595 pin 14 es Serial data  input(DS o SER), Amarillo
#define latchPin 9         // Pur 595 pin 12 es latch (Latch Clock(ST_CP o RCLK), Purpura  ERA PIN 11 ahora en 9, interferia con TONE()
#define clockPin 12        // Gri 595 pin 11 es clock (Shift clock(SH_CP o SRCLK) Gris
#define alarmaPin 13       // Roj Parlante alarma    //Ver20
//(Switch mecanico) para confirmar cierre de caja. SIN pin, solo led con switch es suficiente

//Pines Analogos
int potCPM;                // Azu A0 lectura del potenciometro de velocidad (ciclos por minuto) ,  Leída
int potPI = 0;             // Ama A1 lectura del potenciometro de volumen (pasos por ciclo) ,  Leída
#define SDAPin 4           // Ver SDA de I2C Data (BMP280 purpura, etc)
#define SCLPin 5           // Ama SCL de I2C Clock (BMP280 amarillo, etc)

int CALIBRA = 1;           // Chequeo antes de iniciar operación (1) y en marcha para busca de punto origen motor (2)
// local var en main loop   unsigned long Tinicio = 0L;      // Tiempo de inicio de ciclo en milisegundos, 
int ALARMA = 0;            // Diferentes alarmas (estado de alarma por falla) generada 
                          /* 0= Normal, 
                             1= falla de motor/origen, 
                             2= Falla de origen del brazo, 
                             3= Exceso de presion 
                             4= Presion demasiado baja
                             5= Sobre temperatura
                             6= Sensor 1  presion no detectado
                             7= Sensor 2  presion no detectado           Ver20   
                             8= Humedad demasiado baja              
                             9= Señal de ok
                          */
byte AlarmaLeds = 0;
volatile int ResetAlarma = 0;         // variable for reading the pushbutton status
                          
//Variables para BMP280
BME280I2C::Settings settings1(   //Sensor Proximal si Hay 2 sensores
   BME280::OSR_X1,
   BME280::OSR_X1,
   BME280::OSR_X8,    //Oversampling pressure 8, mayor precision
   BME280::Mode_Forced,
   BME280::StandbyTime_500us,
   BME280::Filter_Off,
   BME280::SpiEnable_False,
   0x77 // I2C address. I2C specific.
);
BME280I2C::Settings settings2(   //Sensor Distal siempre
   BME280::OSR_X1,
   BME280::OSR_X1,
   BME280::OSR_X8,    //Oversampling pressure 8, mayor precision
   BME280::Mode_Forced,
   BME280::StandbyTime_500us,
   BME280::Filter_Off,
   BME280::SpiEnable_False,
   0x76 // I2C address. I2C specific.
);
BME280I2C bme1(settings1);
BME280I2C bme2(settings2);

float FactCorrTemp = 0;    //Para calibrar BMP en base a BME,  Temp1 = temp + FactCorrTemp
            // presion se calibra por ser presion relativa a presion inicial
float temp1(NAN), hum(NAN), pres1(NAN);  //se define como no es un numero
float temp2(NAN), pres2(NAN);    //se define como no es un numero
float cmH2O = -2;           // Presion ultima medida (de sensor2)en cmH2O  Ver20
float presionI1 =0;         // Presion Inicial, Ambiente antes de medición, en hPa
float presionI2 =0;         // Presion Inicial, Ambiente antes de medición, en hPa
bool primeramedida = true;  // para hacer medida dentro de loop, a ver si mide correctamente
float presionMax1 = 0;      //  en cmH2O
float presionMin1 = 0;      //  en cmH2O
float presionMax2 = 0;      //  en cmH2O
float presionMin2 = 0;      //  en cmH2O
#define  TCheqPT 100        // Tiempo en  millis entre chequeos de Presion
unsigned long TultmedPT =0; // Tiempo transcurrido desde ultima medida en  millis 
bool DosSensores = false;   // Si hay dos sensores, es un equipo para activacion por disparo
bool CicloCPM = true;
float presionDisparo = -2;       // Presion de disparo de ciclo   Ver20
const float presionMinDisp = -.3;
const float presionMaxDisp = -5;
//////////////////////////////////////////////////////////////////

//Variables mecánicas
#define  MicroStep 2        // Micropasos utilizados en el driver para suavizar motor (1/Microstep) v09Eq07
const int PasosInsp = 270*MicroStep;   // v20Eq8   Default 270  Pasos maximos por Inspiración (depende de mecanismo usado), 200pasos por vuelta*Microstep, definida (define volumen)v09Eq07
const int PasosMin = 150*MicroStep;    // v20Eq8   Default 150
const bool dirEspira = false;          // dirEspira = 0 es inspira, dirEspira = 1 es espira (si el motor esta conectado inverso, cambiar)
bool dirMotor=!dirEspira;   // Motor siempre empieza con inspiración
#define  Vueltas 2          // para 10 mm diametro, debe dar un maximo de dos vueltas 
bool BrazoHome = false;     // Suponemos que el brazo no esta en posicion correcta
long Tentrepasos = 800L ;   // Tiempo entre pasos para asegurar un numero de ciclos por minuto (Pausa en microsegundos, calculada)Driver permite hasta 20 micros v09Eq07
const long TentrepasosMin = 500L;        // tiempo minimo entre pasos
int regresaorigen = 1;      // Tipo de regreso a Origen
int ciclosCalibra = 0;      // Control de ciclos para recalibrar
//int optVuel = 0;          // Vueltas completas del motor para llegar al punto maximo inspiracion
// varaible local float Trespiro = 0;

void setup() {                

  resetearAlarma();
// inicializamos pines.
  pinMode(alarmaPin, OUTPUT); 
  pinMode(cierrePin, INPUT); 
  pinMode(origenMotPin, INPUT); 
  pinMode(direccionPin, OUTPUT); 
  pinMode(pasosPin, OUTPUT);
  pinMode(botonPin, INPUT);
  pinMode(enablePin, OUTPUT); 
  pinMode(origenBraPin, INPUT);    
  pinMode(latchPin, OUTPUT);
  pinMode(dataPin, OUTPUT);  
  pinMode(clockPin, OUTPUT);
  pinMode(ResetAlarmaPin, INPUT_PULLUP);      // initialize the pushbutton pin as an input:
  attachInterrupt(0, ParaAlarma, FALLING);    // Attach an interrupt to the ISR vector Ver20

  Serial.begin(SERIAL_BAUD);
    while(!Serial) {} // Wait
  Wire.begin();
  
  Serial.println(F("************************Inicializando equipo***************************")); 
  
  Serial.print(F("Probando Sensores: ")); 
  if(!bme1.begin())  Serial.println(F("No hay BME280 sensor 1 Proximal!"));
  switch(bme1.chipModel())  {
     case BME280::ChipModel_BME280:
       Serial.println(F("Sensor1 bien BME280 sensor 1! Success."));
       break;
     case BME280::ChipModel_BMP280:
       Serial.println(F("Sensor1 bien BMP280 sensor 1! No Humidity available."));
       break;
     default:
       Serial.println(F("Found UNKNOWN sensor 1! Error!"));
       ALARMA = 6;
       alarma();
  }
  if(!bme2.begin())  {
      Serial.println(F("No hay BME280 sensor 2 Distal!"));
      ALARMA = 7;
      alarma();
  }
  switch(bme2.chipModel())  {
     case BME280::ChipModel_BME280:
       Serial.println(F("Sensor2 bien BME280 sensor 2! Success."));
       break;
     case BME280::ChipModel_BMP280:
       Serial.println(F("Sensor2 bien  BMP280 sensor 2! No Humidity available."));
       break;
     default:
       Serial.println(F("Found UNKNOWN sensor 2! Error!"));
       ALARMA = 7;
       alarma();
  }
  bme1.read(pres1, temp1, hum);
//  if (temp1 != temp1) {
//   Serial.println(F("Sensor 1 fallando."));   
//     ALARMA = 6;
//     alarma ();
//   }
  bme2.read(pres2, temp2, hum);
//  if (temp2 != temp2) {
//    Serial.println(F("Sensor 2 fallando."));   
//     ALARMA = 7;
//     alarma ();
//  }
  if (temp1 == temp1 && temp2 == temp2)  DosSensores = true;   // Hay dos sensores
  FactCorrTemp = temp2 - temp1;    //Luego siempre Temp1 = temp + FactCorrTemp
  if (DosSensores){
      bme1.read(pres1, temp1, hum);               // Primera medida BMP presion sensor 1:
      if (temp1 != temp1) {
        Serial.println(F("Sensor 1 fallando."));   
        ALARMA = 6;
        alarma ();
      }
/*      presionI1 = pres1;
      Serial.print(presionI1/100);    
      Serial.println(F(" hPa Presión Atmosférica de referencia 1 "));
  //    presionmax = pres1+presionmax;
  //    presionmin = pres1+presionmin;
  //    presionMax1 = ((pres1- presionI1)/100)*1.019744289 ;
  //    presionMin1 = presionMax1 ;
      //    Serial.print(F("pascales "));
      //    Serial.println(pres1);   
      //     Serial.print(F("Presión DISTAL  Máxima: "));
      //     Serial.print(presionMax1);       
      //     Serial.print(F("  Minima:"));
      //     Serial.println(presionMin1); */
  }  
  bme2.read(pres2, temp2, hum);             // Primera medida BMP presion sensor 2:
  if (temp2 != temp2) {
    Serial.println(F("Sensor 2 fallando."));   
    ALARMA = 7;
    alarma ();
  }
 /* presionI2 = pres2;
      Serial.print(presionI2/100);    
      Serial.println(F(" hPa Presión Atmosférica de referencia 2 "));
 // presionMax2 = pres2;
 // presionMin2 = pres2;*/

   //preflight check
//  Tinicio = millis(); 
  digitalWrite(enablePin, HIGH);                      // desactiva el driver del motor
  if (!digitalRead(origenMotPin)) RegresaOrigen();
  Serial.print(F(" RegresaOrigen terminado. Logica Origen y brazo: "));  
  Serial.print(digitalRead(origenMotPin) );
  Serial.println(digitalRead(origenBraPin));
  if (!digitalRead(origenBraPin)){
    ALARMA =2;
    alarma();
  }
  chequeoPT();

/*  delay (1000);
  if (ALARMA > 0){    //no sigue********************************************************
    DEBUG_PRINT(F("DEBUG Alarma activada durante setup. Equipo parqueado ALARMA:"));
    DEBUG_PRINT(ALARMA);  
    TODOMAL();     
  }
    DEBUG_PRINT(F("DEBUG Alarma ALARMA:"));
    DEBUG_PRINT(ALARMA); 
    */
  if (ALARMA == 0) {
    DEBUG_PRINT(F("DEBUG Alarma2 ALARMA:"));
    DEBUG_PRINT(ALARMA); 
    CALIBRA = 0;
    TODOBIEN();   // .........
    resetearAlarma();
  }
}

void chequeoPT() {                                    //chequear presion Sensores 1 y 2
  if (DosSensores){
    bme1.read(pres1, temp1, hum);             // Lectura sensor 1 Proximal (0x77) es BME
    if (pres1 != pres1) {
      Serial.println(F("Sensor 1 fallando."));   
      ALARMA = 6;
      alarma ();
    }
    if (primeramedida){
    //***   nueva lectura para evitar falla inicio presion referencia
    delay(100);
    bme1.read(pres1, temp1, hum);             // Lectura sensor 1 Proximal (0x77) es BME
      presionI1 = pres1;
      Serial.print(presionI1/100);    
      Serial.println(F(" hPa Presión Atmosférica de referencia 1 operando"));
      presionmax = pres1+presionmax;
      presionmin = pres1+presionmin;  
    }
    if (pres1 < presionmin){
        Serial.print(F("bajo MIN Proximal pascal leidos   "));
        Serial.print(pres1);    
        Serial.print(F("    , Pascal mínimos")); 
        Serial.println(presionmin);    
        ALARMA = 4;
        alarma(); 
    }
    if (pres1 > presionmax){
        Serial.print(F("sobre MAX Proximal pascal leidos   "));
        Serial.print(pres1);    
        Serial.print(F("    , Pascal máximos")); 
        Serial.println(presionmax); 
        ALARMA = 3;
        alarma();
    }
    pres1= ((pres1- presionI1)/100)*1.019744289;    // lo convierte en cmH2O
    if (presionMin1 > pres1) presionMin1 = pres1;   //  en cmH2O
    if (presionMax1 < pres1) presionMax1 = pres1;   //  en cmH2O
  } 
      
  bme2.read(pres2, temp2, hum);                      //lectura del sensor 2 Distal (0x76) BMP
  if (pres2 != pres2) {
    Serial.println(F("Sensor 2 fallando."));   
    ALARMA = 7;
    alarma ();
  }
  if (primeramedida){
  //***   nueva lectura para evitar falla inicio presion referencia
  delay(100);
  bme2.read(pres2, temp2, hum);                      //lectura del sensor 2 Distal (0x76) BMP
    Serial.print(pres2/100);    
    Serial.println(F(" hPa Presión Atmosférica de referencia 2 operando"));
      if (!DosSensores) {
        presionI2 = pres2;
        presionmax = pres2+presionmax;
        presionmin = pres2+presionmin; 
      }
    presionMax2 = pres2;
    presionMin2 = pres2;
    primeramedida = false; 
  }
  if (!DosSensores) {
    if ((pres2 - presionmin) < -4000) pres2 = presionmin; //dato malo....................................
    if (pres2 < presionmin){
      Serial.print(pres2);    
      Serial.print(F("Distal pascal leidos      pascal minimos    "));
      Serial.print(presionmin);
      ALARMA = 4;
      alarma(); 
    }
    if (pres2 > presionmax){
      Serial.print(pres2);    
      Serial.print(F("Distal pascal leidos      pascal maximos    "));
      Serial.print(presionmax);
      ALARMA = 3;
      alarma();
    }
  }
  
  pres2= ((pres2 - presionI2)/100)*1.019744289;     // lo convierte en cmH2O
  if (presionMin2 > pres2) presionMin2 = pres2;
  if (presionMax2 < pres2) presionMax2 = pres2;
  
  TultmedPT = millis();
}

void alarma() {           
  if  (ResetAlarma ==1) resetearAlarma();
  
  if (ALARMA >0){                                                     // Alarma sigue hasta interrupt
    DEBUG_PRINTln(F("DEBUG Alarma superior a 0*********************************"));  
    if (ALARMA ==6)Serial.println(F("Sensor 1 distal fallando o ausente"));
    if (ALARMA ==7)Serial.println(F("Sensor 2 proximal fallando o ausente"));
    tone(alarmaPin, 1000);                                        // encender Alarma 
    bitSet(AlarmaLeds, ALARMA-1);
    updateShiftRegister();
  }
}

void TODOBIEN() {                          //señal que anuncia todo bien
   resetearAlarma();
   tone(alarmaPin, 1000);
   delay (500);
   tone(alarmaPin, 2000); 
   delay(1000);
   ALARMA = 0;
}

void TODOMAL(){                             // Sirena cuando para definitivo
  DEBUG_PRINT(F("DEBUG TODOMAL*********************************"));  
  digitalWrite(enablePin, HIGH);        // desactiva el driver del motor 
  int millisPROVI = millis();
  while(millis() < millisPROVI+180000){ // Durante 3 minutos
    for(int index = 7; index >= 0; index--){ 
//      bitSet(AlarmaLeds, index);
//      updateShiftRegister();
      for (int i = 100; i <= 200; i++){   // Emitir sonido sirena problema al final
        tone(alarmaPin, i*4); 
        delay(20);
      }
//      AlarmaLeds =0;
//      updateShiftRegister();
    }
  }
  noTone(alarmaPin);
  parar();
}

void parar(){
   DEBUG_PRINT(F("DEBUG  PARADA ETERNA********************************"));  
   while(1);
}

void resetearAlarma(){
    AlarmaLeds = 0;
    updateShiftRegister();
    ResetAlarma = 0;
    ALARMA =0;
    noTone(alarmaPin); 
}
  
void RegresaOrigen(){
  digitalWrite(enablePin, HIGH);            // desactiva el driver del motor 
  Tentrepasos = TentrepasosMin;             // Maxima aceleracion v09Eq07
  
  if (CALIBRA ==2){                         // Calibracion sobre la marcha de punto de origen, llamada por motor fuera de punto
    dirMotor = !dirEspira;                  // Primera calibracion hacia Inspira (suponemos que salto pasos durante inspira
    potPI = PasosInsp;                      // PasosInsp para recalibrar origen v09Eq07
    DEBUG_PRINT(F("DEBUG  Valor de pasos a moverse durante calibración y dir: "));  
    DEBUG_PRINT(potPI);
    DEBUG_PRINTln(dirMotor);
    MueveMotor();
      Serial.print(" RegresaOrigen sobre la marcha Motor Brazo: ");  
      Serial.print(digitalRead(origenMotPin));
      Serial.println(digitalRead(origenBraPin));
      if (digitalRead(origenMotPin)){         // Si motor regreso a origen
                       DEBUG_PRINTln(F("DEBUG  Hasta aqui llegué8 OrigenMot bien....................."));   
        if (digitalRead(origenBraPin)){       // Todo bien
                       DEBUG_PRINTln(F("DEBUG  Hasta aqui llegué9 OrigeBra bien...................."));   
                       Serial.println(F(" Recalibró en operación "));
          resetearAlarma();   //cuidado resetea todo, talvez deba solo resetear alarma 1 i 2
          potPI = PasosInsp;
          CALIBRA = 0;
        }
        else if (!digitalRead(origenBraPin)){       // Si brazo no llego a origen, Suponemos que se paso una vuelta, y retrocedemos 1 vuelta
          DEBUG_PRINTln(F("DEBUG  brazo no llego a origen, Retrocedemos 7A....................."));   
          dirMotor = dirEspira;
        potPI = PasosInsp;          // v09Eq07
        MueveMotor();   
        if (!digitalRead(origenBraPin)) TODOMAL();       
        }
      }
      else TODOMAL();       //No regresó a origen de motor, algo anda mal. Paraliza la maquina. Reiniciar
  }
  else if (CALIBRA == 1){                              // Calibracion inicial de punto de origen
    int pasoscalib = 10*MicroStep;
    dirMotor = dirEspira;
    for (potPI = pasoscalib; potPI < PasosInsp; potPI= potPI+pasoscalib){        // PasosInsp para limite de pasos v09Eq07 por microstep
      dirMotor = !dirMotor;
      DEBUG_PRINT(F("DEBUG  Valor de pasos a moverse durante calibración y dir: "));  
      DEBUG_PRINTln(potPI);
      MueveMotor();
      DEBUG_PRINT("DEBUG  RegresaOrigen inicial : ");  
      DEBUG_PRINTln(digitalRead(origenMotPin) );
      if (digitalRead(origenMotPin) && digitalRead(origenBraPin)){
        DEBUG_PRINTln(F("DEBUG  DEBE PASAR POR ACA................................: "));
        potPI = PasosInsp;
        TODOBIEN();
        CALIBRA = 0;
      }
    }  
    if (!digitalRead(origenMotPin) || !digitalRead(origenBraPin)){ ;
      ALARMA = 1;
      alarma(); 
    }
  }
}

void MueveMotor() {
  int optLog = 0;
  int optVue = 0;
  digitalWrite(enablePin, LOW);         // Activa el driver del motor
  DEBUG_PRINT(F("DEBUG  Hasta aqui llegué4.............POTPI, dirMotor........"));
  DEBUG_PRINT(potPI);
  DEBUG_PRINTln(dirMotor);
  if ((10000 < Tentrepasos) || (Tentrepasos < TentrepasosMin)){
    Serial.print(F("  Microsegundos de pausa entre pasos (Tentrepasos)fuera de rango: "));
    Serial.println(Tentrepasos);
    Tentrepasos = TentrepasosMin;  //*******************************************
  }
  for (int i = 0; i <= potPI; i++) {    // BUCLE DE PASOS que mueven motor
    digitalWrite(direccionPin, dirMotor);    // inhala o retrocede
    digitalWrite(pasosPin, HIGH);       // Aqui generamos un flanco de bajada HIGH - LOW menos el tiempo de medicion
    delayMicroseconds(Tentrepasos);     // Pequeño retardo para formar el pulso en STEP DQ era 10
    digitalWrite(pasosPin, LOW);        // y el driver de avanzara un paso el motor
    delayMicroseconds(Tentrepasos);     // Retardo para llegar a una velocidad de ciclo menos el tiempo de medicion
 
    if (CALIBRA == 0 ){                                            // Durante operacion normal
      if (digitalRead(origenMotPin) == optLog ){                      // Lleva control de las veces que se pasa el punto de origen del motor (vueltas)
        optLog = !optLog;
        if (optLog == 0) optVue = optVue + 1;
      }
      if (millis() - TultmedPT > TCheqPT) chequeoPT();
      if (ALARMA != 0) alarma();
      if (optVue > Vueltas && dirMotor == !dirEspira && i>= 100) { // En inspiracion, Parar avance cuando llego a punto de origen 
                                                                   // (desinflado maximo AMBU), exceso de pasos    PROBABLEMENTE INNECESARIO
        DEBUG_PRINT(F("DEBUG Se pasa de vueltas........"));
        digitalWrite(enablePin, HIGH);                             // desactiva el driver del motor
        ALARMA = 1;
        break;
      } 
    }
    else if (CALIBRA >0){                                           // Durante calibracion punto origen, para salir en cuanto llega a origen
//    delay (1);
      if (digitalRead(origenMotPin) && digitalRead(origenBraPin)){  // Si ambos puntos de origen OK
        digitalWrite(enablePin, HIGH);                              // desactiva el driver del motor
        i=potPI;                                                    // Termina movimientos saliendo del bucle de pasos
      }
    }    
  }                                     // FIN BUCLE DE PASOS que mueven motor
  
  if (DosSensores){
    bme1.read(pres1, temp1, hum); 
    if (temp1 > tempmax){
      ALARMA = 5;
      alarma(); 
    }
  }
  else {
    bme2.read(pres1, temp1, hum); 
    if (temp1 > tempmax){
      ALARMA = 5;
      alarma(); 
    }
  }
                      DEBUG_PRINTln(F("DEBUG  Fin de MueveMotor 6....................."));   
}

void loop() {
   if (ALARMA != 0) alarma();
   
/*  If low and un sensor suspende bucle
  if high and un sensor ciclo RPM
  If low and dos sensores ciclo disparo
  if high and dos sensores ciclo RPM

*/
 while (digitalRead(botonPin) == LOW && !DosSensores)(1);    //En CPM un sensor no hace nada mientras no encienda 
   Tinicio = millis();                  // Marca tiempo de inicio de la respiración
   potPI = map(analogRead(A1),0,1023,PasosMin,PasosInsp);         // leemos numero de pasos para inspiración, lo cual definirá volumen 
   
   if (digitalRead(botonPin) == HIGH ){     // leemos el boton de encendido. Si esta encendido, es por RPM
     CicloCPM = true;
     potCPM = map(analogRead(A0),0,1023,ciclosmin*10,ciclosmax*10); // leemos Ciclos por minuto y adaptamos el valor a un numero de (decimos de) ciclo por minuto, entre min y max (para  rangos mas precisos)
     CPM =  potCPM;
     CPM =  CPM/10;
     TCiclo = 60000/CPM; 
    //*****************************************
     Tentrepasos = ((((TCiclo*1000L-TMeseta*1000L) * FInsp)/(potPI*.8))/ (MicroStep*sqrt(MicroStep)));    // Tiempo entre pasos en microsegundos dividido por los micropasos  // Ciclo en milisegundos
    //////     if (Tentrepasos > 987 + TentrepasosMin)  Tentrepasos = Tentrepasos - 987;      //987microsegundos es tiempo adicional por medio paso dedicado a mediciones y calculos (por dos)
     Serial.println();
     Serial.println(F("****************Nuevo Respiro**************"));
     Serial.print(F("  Microsegundos de pausa entre pasos (Tentrepasos): "));
     Serial.println(Tentrepasos);
   }
   else if (DosSensores){  // Si el boton de encendido esta apagado, y hay dos sensores. es un ciclo por disparo (intento inspiratorio)
      CicloCPM = false;
      CPM =  25;
      TCiclo = 60000/CPM;  
      Tentrepasos = TentrepasosMin*1.5;    //Establecemos la velocidad a un respiro normal de 600cc a 25 CPM
      int PotpresionDisparo = map(analogRead(A0),0,1023,presionMaxDisp*100,presionMinDisp*100); // leemos Presion de disparo de ciclo   
      presionDisparo = PotpresionDisparo/100;
      Serial.println(F("****************Esperando disparo Respiro**************"));
      while (presionDisparo < pres1){
        chequeoPT();      //****************Espera el disparo
        if (ResetAlarma) resetearAlarma();
        if (digitalRead(botonPin) == HIGH ){     // SALIR, se cambio a modo de ciclos por minuto sobre la marcha
          potCPM = map(analogRead(A0),0,1023,ciclosmin*10,ciclosmax*10); // leemos Ciclos por minuto y adaptamos el valor a un numero de (decimos de) ciclo por minuto, entre min y max (para  rangos mas precisos)
          CPM =  potCPM;
          CPM =  CPM/10;
          TCiclo = 60000/CPM; 
          Tentrepasos = ((((TCiclo*1000L-TMeseta*1000L) * FInsp)/(potPI/2))/ (MicroStep*sqrt(MicroStep)));
          break;   // se cambio a modo de ciclos por minuto sobre la marcha
        }
        /*DEBUG_PRINT("DEBUG Presion segun sensor en cmH2O:");
        DEBUG_PRINTln(pres1);
        DEBUG_PRINT("DEBUG Presion disparo en cmH2O:");
        DEBUG_PRINTln(presionDisparo);*/
      }
      Serial.println(F(" Respiro disparado......................."));
    }
 
// CICLO INSPIRACION   
      dirMotor = !dirEspira;
      MueveMotor();
      unsigned long iniciomeseta = millis();                      //Meseta
      while (millis() -iniciomeseta < TMeseta){
        if (millis() - TultmedPT > TCheqPT) chequeoPT();
      }
      //      if (ALARMA == 1) RegresaOrigen();// Modificar: si brazo no en origen, o motor no en origen, regresaorigen. si no resuelve: ALARMA
      unsigned long Tinspira = millis()-Tinicio;                  // Guarda duracion de inspiración

// CICLO ESPIRACION        
      Tentrepasos = TentrepasosMin;            // Maxima aceleracion v09Eq07;   // acelerando espiracion era 600 (microsegundos)v09Eq07
      dirMotor = dirEspira;
      MueveMotor();
      digitalWrite(enablePin, HIGH);                              // desactiva el driver del motor, regresa a origen si AMBU presionado
      DEBUG_PRINT(F("DEBUG  Hasta aqui llegué ESPIRA..............CicloCPM:"));
      DEBUG_PRINTln(CicloCPM);
      
// Pausa restante para ciclos por minuto establecidos en millis (solo en CPM)
      if (CicloCPM){
        pausita = (TCiclo - (millis()- Tinicio));
        DEBUG_PRINT(F(" TCiclo en milis:"));
        DEBUG_PRINTln(TCiclo);
        DEBUG_PRINT(F(" Pausita en milis:"));
        DEBUG_PRINTln(pausita);
        if (3000>pausita && pausita>100){
          unsigned long  iniciopausita = millis();
          DEBUG_PRINTln (millis()- iniciopausita);
          while (millis() - iniciopausita < pausita){    
            //DEBUG_PRINT (millis()- iniciopausita);
            if (millis() - TultmedPT > TCheqPT) chequeoPT();        // Si paso el tiempo para medir, medir
          }
        }
      }
      
      if (!digitalRead(origenMotPin) || !digitalRead(origenBraPin) ){ 
        CALIBRA = 2;
              DEBUG_PRINTln(F("DEBUG Hay que recalibrar2 ......................."));
              RegresaOrigen();  
                    DEBUG_PRINTln(F("DEBUG  Post recalibrada3....................."));
  Serial.println(F("Recalibró origen."));
         ciclosCalibra = 0;
         CALIBRA = 0;
      }
    
//cada hora, recalibra contra presion atmosferica.........................................................******************************************************
//Reporte del ciclo respiratorio

     float Trespiro = millis()- Tinicio;      //Duracion respiro 
     Serial.print(F(" Fin respiro. Duración: "));
     Serial.println(Trespiro/1000); 
     Serial.print(F(" Ciclos por minuto planteados (CPM) / efectivos (60/(Trespiro/1000)) : " ));
     Serial.print(CPM);
     Serial.print(F(" / "));
     Serial.println(60/(Trespiro/1000));
     Serial.print(F(" Fraccion Inspiratoria incluyendo meseta (Tinspira/Trespiro): "));
     Serial.println(Tinspira/Trespiro);
     Serial.print(F(" Milisegundos de pausa al final de espiracion (pausita): "));
     Serial.println(pausita);
     Serial.print(F(" Presión Proximal Máxima: "));
     Serial.print(presionMax1);       
     Serial.print(F("  Minima: "));
     Serial.println(presionMin1);   
     Serial.print(F(" Temperatura: "));
     Serial.println(temp1);
     Serial.print(F(" Minutos desde inicio del respirador:  "));
     Serial.println(millis()/60000);
/*     DEBUG_PRINTln();
     DEBUG_PRINT(F("  Numero de pasos por este ciclo (PotPI): "));
     DEBUG_PRINTln(potPI);
     DEBUG_PRINT(F("  Tiempo del ciclo en milisegundos (TCiclo): "));
     DEBUG_PRINTln(TCiclo);
     DEBUG_PRINT(F("  Microsegundos de pausa entre pasos (Tentrepasos): "));
     DEBUG_PRINTln(Tentrepasos);
     DEBUG_PRINTln();
     */
  presionMax1 = 0;              //resetea los valores Presion del ciclo
  presionMin1 = 0;
  presionMax2 = 0;
  presionMin2 = 0;
  if  (ALARMA ==0) resetearAlarma();
}
//FIN DE MAIN LOOP

void updateShiftRegister(){
   digitalWrite(latchPin, LOW);
   shiftOut(dataPin, clockPin, MSBFIRST, AlarmaLeds);
   digitalWrite(latchPin, HIGH);
}

void ParaAlarma() {    //Interrupt para leer el boton de reset Ver20
  ResetAlarma = 1;
}

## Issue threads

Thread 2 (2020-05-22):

Usar interrupt para señales de advertencia, sin interrumpir el programa de respiracion

DQUEROL, 2020-05-22:
void alarma() {           //habria que hacerlo como interrupt para advertencias que no paren la maquina...............
       if (ALARMA ==6)     Serial.println("Sensor fallando o ausente");
       if (ALARMA != 2)  digitalWrite(enablePin, HIGH);   // desactiva el driver del motor
    while (ALARMA >0){                       // Alarma sigue hasta reinicio, a menos que haya break (fallas menores)
//      delay(100); // pequeña pausa
      for (int j = 1; j <= 10; j++){         // Suena 10 veces el numero de la alarma
          if (ALARMA ==2) j=10;
          for (int k =1; k<= ALARMA; k++){   // Señal por numero de alarma
            tone(alarmaPin, 1000, 500);
            delay (500);
          }
          if (ALARMA ==2) break;
          delay (1000);
      }
      if (ALARMA ==2) break;

      tone(alarmaPin, 2000, 500);
      for (int i = 100; i <= 200; i++){       // Emitir sonido sirena problema al final
        tone(alarmaPin, i*4);
        delay(20);
      }
    }
}

DQUEROL, 2020-06-21:
Resuelto usando interrupt

DQUEROL, 2020-06-21:
Solved using interrupt

Closed 2020-06-21.

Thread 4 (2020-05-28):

Public Invention: Vent-mon

avinashbaskaran, 2020-05-28:
Hello Daniel,

My name is Avinash Baskaran, we have been interacting through https://github.com/PubInv/covid19-vent-list/issues.

I just wanted to make you aware of the Vent-mon, an instrumented test long which may be made available to you for free for testing of your device (https://github.com/PubInv/ventmon-ventilator-inline-test-monitor). If you would like to learn more, please reach out to Dr. Robert Read at read.robert@gmail.com.

DQUEROL, 2020-05-28:
Hello Robert

My name is Daniel Querol, and I am working on 59 Respirador-DQ3D-NICA
(#128) <https://github.com/DQUEROL/Respirador-DQ3D-NICA>. In Nicaragua I
have been unable to get access to a Test lung, and have been calibrating
my pressures (measured with two BMP280s) with a water column. Volume has
been estimated with a tub and a graduated vessel...

Your Vent-mon would be a great improvement for testing and calibration
efforts. Could you send me one either to Nicaragua via DHL or to Miami,
where a friend would convey it to me?

Thank you in advance

Yours truly

Daniel Querol

P.S. Great job you are doing with the Ventilator projects analysis. As I
have not found Peers in Nicaragua, it is helping me in channeling
efforts to solve the weaknesses you detect.

DQ

El 27/05/2020 a las 07:25 p. m., Avinash Baskaran escribió:
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

--
Este correo electrónico ha sido comprobado en busca de virus por AVG.
http://www.avg.com

DQUEROL, 2020-05-28:
Yes, we will absolutely send you one free-of-charge as soon as we can make
another one; the world-wide supply chain crunch on flow sensors has created
a problem for us building them. We are working as fast as we can to find an
alternative.

Lauria, can you please add Daniel Querol in Nicaragua to our list?

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

--
Robert L. Read, PhD
Twitter: @RobertLeeRead @pubinvention
Public Invention: https://www.pubinv.org
Join Our Mailing list: pubinv@googlegroups.com
YouTube: https://www.youtube.com/channel/UCJQg_dkDY3KTP1ybugYwReg
Medium: https://medium.com/@RobertLeeRead

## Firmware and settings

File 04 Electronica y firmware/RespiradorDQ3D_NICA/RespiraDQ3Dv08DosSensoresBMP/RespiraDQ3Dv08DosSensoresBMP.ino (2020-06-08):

/* Control de respirador DQ3D NICA
 * Mayo 2020
 * 
 * Arduino Nano 
 * Motor Nema23
 * DQ3D.org
 */

//incluir librerias necesarias para sensores
#include <Wire.h>
#include "i2c.h"
#include "i2c_BMP280.h"     //manejador de sensor I2C 1
BMP280 bmp280;
#include "i2c_BMP2802.h"    //manejador de sensor I2C 2
BMP2802 bmp2802;
#include "MegunoLink.h"     //manejador de graficas seriales
TimePlot MyPlot;            //no channel selected

//Variables médicas modificables en firmware
int   ciclosmin = 16;     // Minimo de ciclos por minuto
int   ciclosmax = 25;     // Maximo de ciclos por minuto
float FInsp = .42;        // fracción inspiratoria = Tiempo Inspiracion/Tiempo total ciclo (.42 recomendado) SE PUEDE PONER UN POTENCIOMETRO PARA VARIAR
unsigned long TMeseta = 600 ;     // Tiempo de Meseta en milisegundos (Max600)(Presión alta mantenida antes de pasar a Exhalación)
unsigned long Pausa = 0;          // Duracion de la pausa adicional entre mareas en milisegundos,  
float presionmax = 2942;  // Presion maxima en cualquier momento en Pascal. 30cmH2O     PARA EL EQUIPO.
float presionmin = -490;  // Presion minima durante espiracion en Pascal. -5cmH2O       Señal advertencia
float tempmax = 39;       // Temperatura maxima del aire
                          // volumen segun ambu y posicion del reostato

//Variables medicas derivadas
float CPM = ciclosmin;    // Ciclos por minuto inicio
float TCiclo = 60/CPM;    // duración del ciclo respiratorio (s)

//Definición pines Digitales y Análogos
const int ResetAlarmaPin = 2;   // (Interrupt) Boton reset alarma
const int cierrePin = 3;        // (Interrupt) Pin libre
const int origenMotPin = 4;     // Pin de sensor optico para confirmar si Motor regresó a origen. No se han saltado pasos (motor en posicion adecuada) despues de un ciclo
const int direccionPin = 5;     // Pin direccion Motor 
const int pasosPin = 6;         // Pin step pasos Motor
const int botonPin = 7;         // Pin pulsador  (encendido ciclo)
const int enablePin = 8;        // Pin activa y desactiva motor Motor (Verificar con el driver. Driver HY-DIV268N 6600 activa motor con LOW.
const int origenBraPin = 9;     // Pin (endstop) para confirmar brazo en punto de partida
const int SPIssPin = 10;        // Reservado para SPI
const int SPImosiPin = 11;      // Reservado para SPI
const int SPImisoPin = 12;      // Reservado para SPI
const int alarmaPin = 13;       // Boton reset alarma
//(Switch mecanico) para confirmar cierre de caja. SIN pin, solo led con switch es suficiente

int potCPM;                     // A0 lectura del potenciometro de velocidad (ciclos por minuto) ,  Leída
int potPI = 0;                  // A1 lectura del potenciometro de volumen (pasos por ciclo) ,  Leída 
const int SDAPin = 4;           // Reservado para SDA de I2C Data (BMP280 purpura, etc)
const int SCLPin = 5;           // Reservado para SCL de I2C Clock (BMP280 amarillo, etc)

int CALIBRA = 1;                // Chequeo antes de iniciar operación (1) y en marcha para busca de punto origen motor (2)
unsigned long Tinicio = 0;      // Tiempo de inicio de ciclo en milisegundos, 
unsigned long TultimaAlarma =0; // cuando se paso por la alarma
unsigned long TultimaSerieAlarma = 0; // Tiempo de inicio de la serie
unsigned long tiempoAlarma = 500;     // Tiempo del pitido de alarma en milisegundos
int pitosAlarma = 0;            // Numero de pitos tocados por alarma
bool alarmaON = false;
int ALARMA = 0;           // Diferentes alarmas (estado de alarma por falla) generada 
                          /* 0= Normal, 
                             1= falla de motor/origen, 
                             2= Falla de origen del brazo, 
                             3= Exceso de presion 
                             4= Presion demasiado baja
                             5= Sobre temperatura
                             6= Sensor presion no detectado
                             9= Señal de ok
                          */
volatile int ResetAlarma = 0;         // variable for reading the pushbutton status
                          
//Variables para BMP280
float temperature, pascal;  // Crea las variables de temperatura y presion 
float cmH2O;                // Presion en cmH2O
float presionI1 =0;         // Presion Inicial, Ambiente antes de medición, en hPa
float presionI2 =0;         // Presion Inicial, Ambiente antes de medición, en hPa
float presionMax1 = 0;      //  en cmH2O
float presionMin1 = 0;      //  en cmH2O
float presionMax2 = 0;      //  en cmH2O
float presionMin2 = 0;      //  en cmH2O
int j =0;
unsigned long TCheqPT = 100;// Tiempo en  millis entre chequeos de Presion
unsigned long TultmedPT =0; // Tiempo transcurrido desde ultima medida en  millis 

//Variables mecánicas
const int PasosInsp = 550;  // Pasos maximos por Inspiración (depende de mecanismo usado), 200pasos por vuelta*Microstep, definida (define volumen)
const int MicroStep = 2;    // Micropasos utilizados en el driver para suavizar motor (1/Microstep)
const bool dirEspira = false;   // dirEspira = 0 es inspira, dirEspira = 1 es espira (si el motor esta conectado inverso, cambiar)
bool dirMotor=!dirEspira;   // Motor siempre empieza con inspiración
const int Vueltas = 2;      // para 10 mm diametro, debe dar un maximo de dos vueltas 
bool BrazoHome = false;     // Suponemos que el brazo no esta en posicion correcta
int Tentrepasos = 900 ;     // Tiempo entre pasos para asegurar un numero de ciclos por minuto (Pausa en microsegundos, calculada)
int regresaorigen = 1;      // Tipo de regreso a Origen
//int optVuel = 0;          // Vueltas completas del motor para llegar al punto maximo inspiracion
//float Trespiro = 0;
//bool Activa = false;      //   Logica (encendida o apagada) ,  Leída

// variables provisionales para grafica MegunoLink
int ipagra = 0;
int inpagra =10;    //solo envia señal cada 10 medidas
float iprompagra = 0;
float iprompagra2 = 0;

void setup() {                
  
  // inicializamos pines.
  pinMode(alarmaPin, OUTPUT); 
  pinMode(cierrePin, INPUT); 
  pinMode(origenMotPin, INPUT); 
  pinMode(direccionPin, OUTPUT); 
  pinMode(pasosPin, OUTPUT);
  pinMode(botonPin, INPUT);
  pinMode(enablePin, OUTPUT); 
  pinMode(ResetAlarmaPin, INPUT_PULLUP);      // initialize the pushbutton pin as an input:
  attachInterrupt(0, pin_ISR, FALLING);       // Attach an interrupt to the ISR vector
  
  Serial.begin(230400);

//   MegunoLink      //manejador de graficas seriales
  MyPlot.SetTitle("Presiones en tuberia");
  MyPlot.SetXlabel("Tiempo (min)");
  MyPlot.SetYlabel("Presion (cmH2O)");
  MyPlot.SetSeriesProperties("Distal", Plot::Blue, Plot::Solid, 1, Plot::NoMarker);
  MyPlot.SetSeriesProperties("Proximal", Plot::Red, Plot::Solid, 1, Plot::NoMarker);

  
  Serial.print("Probando BMP280: ");
  //...................................................Verificar si usando BMP solo cuando se necesita.......
  if (bmp280.initialize()) Serial.println("Sensor1 bien");
  else    {
      ALARMA = 6;
      alarma();
  //    while (1) {}
  }
// Primera medida BMP presion sensor 1:
  bmp280.setEnabled(1);
  bmp280.awaitMeasurement();
  bmp280.getTemperature(temperature);
  bmp280.getPressure(pascal);
  presionI1 = pascal;
  Serial.print(presionI1/100);    
  Serial.println(F(" hPa Presión Atmosférica de referencia 1 "));
  presionmax = pascal+presionmax;
  presionmin = pascal+presionmin;
  presionMax1 = ((pascal- presionI1)/100)*1.019744289 ;
  presionMin1 = presionMax1 ;
 /*    Serial.print(F("pascales "));
     Serial.println(pascal);   
     Serial.print(F("Presión DISTAL  Máxima: "));
     Serial.print(presionMax1);       
     Serial.print(F("  Minima:"));
     Serial.println(presionMin1); 
*/
// Primera medida BMP presion sensor 2:
  if (bmp2802.initialize()){
    Serial.println("Sensor2 bien");
    bmp2802.setEnabled(1);
    bmp2802.awaitMeasurement();
    bmp2802.getTemperature(temperature);
    bmp2802.getPressure(pascal);
    presionI2 = pascal;
  //      Serial.print(presionI2/100);    
  //      Serial.println(F(" hPa Presión Atmosférica de referencia 2 "));
    presionMax2 = ((pascal- presionI1)/100)*1.019744289 ;
    presionMin2 = presionMax2;
  }  
  else    {
    Serial.println(F(" Sensor 2 Ausente "));
  }

//preflight check
//  Tinicio = millis(); 
  digitalWrite(enablePin, HIGH);                      // desactiva el driver del motor
  if (!digitalRead(origenMotPin)) RegresaOrigen();
Serial.print(" RegresaOrigen terminado. Logica Origen y brazo: ");  
Serial.print(digitalRead(origenMotPin) );
Serial.println(digitalRead(origenBraPin));
  if (!digitalRead(origenBraPin)){
    ALARMA =2;
    alarma();
  }
  CALIBRA = 0;
  TODOBIEN();   // Problema si alarma encendida...................................................
}

void chequeoPT() {                                    //chequear presion Sensores 1 y 2
    bmp280.getPressure(pascal);
    if (pascal < presionmin){
      Serial.print(pascal);    
      Serial.print(F("DISTAL pascal leidos      pascal minimos    "));
      Serial.print(presionmin);
      ALARMA = 4;
      alarma(); 
    }
    if (pascal > presionmax){
      Serial.print(pascal);    
      Serial.print(F("DISTAL pascal leidos      pascal maximos    "));
      Serial.print(presionmax);
      ALARMA = 3;
      alarma();
    }
    float pascalH2O= ((pascal- presionI1)/100)*1.019744289;    // lo convierte en cmH2O
//    MyPlot.SendFloatData(F("Distal"),pascal, 1);    // Distal = nombre de la serie, pascal  = data to plot
    if (presionMin1 > pascalH2O) presionMin1 = pascalH2O;   //  en cmH2O
    if (presionMax1 < pascalH2O) presionMax1 = pascalH2O;   //  en cmH2O

         
/*    bmp2802.getPressure(pascal);                      //lectura del sensor 2 (77)
    if (pascal < presionmin){
      Serial.print(pascal);    
      Serial.print(F("PROXIMAL pascal leidos      pascal minimos    "));
      Serial.print(presionmin);
      ALARMA = 4;
      alarma(); 
    }
    if (pascal > presionmax){
      Serial.print(pascal);    
      Serial.print(F("PROXIMAL pascal leidos      pascal maximos    "));
      Serial.print(presionmax);
      ALARMA = 3;
      alarma();
    }
    pascalH2O= ((pascal - presionI2)/100)*1.019744289;     // lo convierte en cmH2O
//    MyPlot.SendFloatData(F("Proximal"),pascal, 1);    // Proximal = nombre de la serie, pascal  = data to plot
    if (presionMin2 > pascalH2O) presionMin2 = pascalH2O;
    if (presionMax2 < pascalH2O) presionMax2 = pascalH2O;
*/    
  TultmedPT = millis();
}

void alarma() {           
  if  (ResetAlarma ==1){
    ResetAlarma = 0;
    ALARMA =0;
    noTone(alarmaPin);  
  }
  
  if (ALARMA >0){                 // Alarma sigue hasta reinicio, a menos que haya break (fallas menores)
    if (ALARMA ==6)     Serial.println("Sensor fallando o ausente");
    if (!alarmaON){
      if(pitosAlarma < ALARMA){   // Señal por numero de alarma
        tone(alarmaPin, 1000);    // encender por tiempoAlarma milis
        TultimaAlarma = millis();
        alarmaON = true;
      }
      //iniciar pausa entre serie de pitidos
      else if (pitosAlarma >= ALARMA && millis()-TultimaSerieAlarma >= (tiempoAlarma+200)*(ALARMA-1) + 1000){  
        alarmaON = false;
        pitosAlarma = 0;
        TultimaSerieAlarma =millis();;
      }
    }
    
    if (alarmaON){ 
      if( millis()-TultimaAlarma >= tiempoAlarma){          // para el pitido por cumplir tiempo
        noTone(alarmaPin);
        if (millis()-TultimaAlarma >= tiempoAlarma + 200){  // 200 de pausa entre pitidos
          pitosAlarma = pitosAlarma +1;
          alarmaON = false;
        }
      }
    }
  }

} 

void TODOBIEN () {                        //señal que anuncia todo bien
   tone(alarmaPin, 1000, 1000);
   delay (500);
   tone(alarmaPin, 2000, 1500); 
}

void TODOMAL(){                           // Sirena cuando para definitivo
    while(1){
      for (int i = 100; i <= 200; i++){   // Emitir sonido sirena problema al final
        tone(alarmaPin, i*4); 
        delay(20);
      }
      delay (1000);
    }
}

void RegresaOrigen(){
  digitalWrite(enablePin, HIGH);               // desactiva el driver del motor 
  
  if (CALIBRA ==2){               // Calibracion sobre la marcha de punto de origen, llamada por motor fuera de punto
    Tentrepasos = 600;            // Maxima aceleracion
    dirMotor = !dirEspira;        // Primera calibracion hacia Inspira (suponemos que salto pasos durante inspira
    potPI = 1000;                 // PasosInsp para recalibrar origen
    MueveMotor();
    if (digitalRead(origenMotPin)){            // Si motor regreso a origen
      if (digitalRead(origenBraPin)){   //Todo bien
//      Serial.print(" Recalibró en operación................................: ");
        potPI = PasosInsp;
        CALIBRA = 0;
//        break;
      }
      else if (!digitalRead(origenBraPin)){        // Si brazo no llego a origen, Suponemos que se paso una vuelta, y retrocedemos 1 vuelta
            dirMotor = dirEspira;
            potPI = 200*MicroStep;
            MueveMotor();   
            if (!digitalRead(origenBraPin)) TODOMAL();       
      }
    }
    else TODOMAL();       //No regresó a origen de motor, algo anda mal. Paraliza la maquina. Reiniciar
  }
  else if (CALIBRA == 1){                              // Calibracion inicial de punto de origen
    dirMotor = dirEspira;
    for (potPI = 50; potPI < PasosInsp; potPI= potPI+50){        // PasosInsp para limite de pasos
      dirMotor = !dirMotor;
      Serial.print(" Valor de pasos a moverse durante calibración y dir: ");  
      Serial.println(potPI);
      MueveMotor();
      Serial.print(" RegresaOrigen Origen : ");  
      Serial.println(digitalRead(origenMotPin) );
      if (digitalRead(origenMotPin) && digitalRead(origenBraPin)){
        Serial.print(" DEBE PASAR POR ACA................................: ");
        potPI = PasosInsp;
        TODOBIEN();
        CALIBRA = 0;
      }
    }  
    if (!digitalRead(origenMotPin) || !digitalRead(origenBraPin)){ ;
      ALARMA = 1;
      alarma(); 
    }
  }
}

void MueveMotor() {
  int optLog =0;
  int optVue = 0;
  digitalWrite(enablePin, LOW);         // Activa el driver del motor
  for (int i = 0; i <= potPI; i++) {    // BUCLE DE PASOS
    digitalWrite(direccionPin, dirMotor);    // inhala o retrocede
    digitalWrite(pasosPin, HIGH);       // Aqui generamos un flanco de bajada HIGH - LOW menos el tiempo de medicion
    delayMicroseconds(Tentrepasos);     // Pequeño retardo para formar el pulso en STEP DQ era 10
    digitalWrite(pasosPin, LOW);        // y el driver de avanzara un paso el motor
    delayMicroseconds(Tentrepasos);     // Retardo para llegar a una velocidad de ciclo menos el tiempo de medicion
    
    if (digitalRead(origenMotPin) == optLog ){                      // Lleva control de las veces que se pasa el punto de origen del motor (vueltas)
      optLog = !optLog;
      if (optLog == 0) optVue = optVue + 1;
    }
 
    if (CALIBRA == 0 ){                                            // Durante operacion normal
      if (millis() - TultmedPT > TCheqPT) chequeoPT();
      if (ALARMA != 0) alarma();
      if (optVue > Vueltas && dirMotor == !dirEspira && i>= 100) { // En inspiracion, Parar avance cuando llego a punto de origen (desinflado maximo AMBU), exceso de pasos    PROBABLEMENTE INNECESARIO
        digitalWrite(enablePin, HIGH);                             // desactiva el driver del motor
        ALARMA = 1;
        break;
      } 
    }
    else if (CALIBRA >0){                                           // Durante calibracion punto origen, para salir en cuanto llega a origen
//    delay (1);
      if (digitalRead(origenMotPin) && digitalRead(origenBraPin)){  // Si ambos puntos de origen OK
        digitalWrite(enablePin, HIGH);                              // desactiva el driver del motor
        i=potPI;                                                    // Termina movimientos saliendo del bucle de pasos
      }
    }    
  }                                     // FIN BUCLE DE PASOS
  
  bmp280.getTemperature(temperature);    
  if (temperature > tempmax){
    ALARMA = 5;
    alarma(); 
  }

}

void loop() {
   Tinicio = millis();                  // Marca tiempo de inicio de la respiración
   if (ALARMA != 0)alarma();
   
   potCPM = map(analogRead(A0),0,1023,ciclosmin*10,ciclosmax*10); // leemos Ciclos por minuto y adaptamos el valor a un numero de (decimos de) ciclo por minuto, entre min y max (para  rangos mas precisos)
   CPM =  potCPM;
   CPM =  CPM/10;
   TCiclo = 60/CPM;                                               // Ciclo en segundos
   potPI = map(analogRead(A1),0,1023,300,PasosInsp);              // leemos numero de pasos para inspiración, lo cual definirá volumen 
   Tentrepasos = (((TCiclo*1000000 *FInsp) / potPI)/ MicroStep);  // Tiempo entre pasos en microsegundos dividido por los micropasos
   
   if (digitalRead(botonPin) == HIGH){                            // leemos el boton de encendido. Funciona solo si encendido (switch)
   
// CICLO INSPIRACION   
      dirMotor = !dirEspira;
      MueveMotor();
      unsigned long iniciomeseta = millis();                      //Meseta
      while (millis() -iniciomeseta < TMeseta){
        if (millis() - TultmedPT > TCheqPT) chequeoPT();
      }
      //      if (ALARMA == 1) RegresaOrigen();// Modificar: si brazo no en origen, o motor no en origen, regresaorigen. si no resuelve: ALARMA
      unsigned long Tinspira = millis()-Tinicio;                  // Guarda duracion de inspiración

// CICLO ESPIRACION        
      Tentrepasos = 600;                                          // acelerando espiracion (microsegundos)
      dirMotor = dirEspira;
      MueveMotor();
      digitalWrite(enablePin, HIGH);                              // desactiva el driver del motor, regresa a origen si AMBU presionado

// Pausa restante para ciclos por minuto establecidos en millis
      unsigned long pausita = (TCiclo*1000 - (millis()- Tinicio)) + Pausa;
      if (pausita>100){
        unsigned long  iniciopausita = millis();
        while (millis() - iniciopausita < pausita){    
          if (millis() - TultmedPT > TCheqPT) chequeoPT();        // Si paso el tiempo para medir, medir
        }
      }
      
      if (!digitalRead(origenMotPin) || !digitalRead(origenBraPin) ){ 
        CALIBRA = 2;
        RegresaOrigen();  
        Serial.println("                            Recalibró origen.");
        CALIBRA = 0;
      }
    
//cada hora, recalibra contra presion atmosferica.........................................................

                                                                  //Reporta datos Msg Usando MegunoLink
     Message Msg; // Message Monitor will display 
Msg.Begin(); // Message Monitor will display 
     float Trespiro = millis()- Tinicio;      //Duracion respiro 
     Serial.print(" Fin respiro. Duración: ");
     Serial.println(Trespiro/1000); 
     Serial.print(" Ciclos por minuto planteados / efectivos: " );
     Serial.print(CPM);
     Serial.print("\t");
     Serial.println(60/(Trespiro/1000));
     Serial.print(" Fraccion Inspiratoria incluyendo meseta: ");
     Serial.println(Tinspira/Trespiro);
     Serial.print(" Milisegundos de pausa al final de espiracion: ");
     Serial.println(pausita);
     Serial.print(F("Presión DISTAL  Máxima: "));
     Serial.print(presionMax1);       
     Serial.print(F("  Minima:"));
     Serial.println(presionMin1);   
     Serial.print(" Temperatura:  ");
     Serial.println(temperature);
     Serial.print(" Minutos desde inicio del respirador:  ");
     Serial.println(millis()/60000);
     Serial.println();
Msg.End();
   }
  presionMax1 = 0;              //resetea los valores Presion del ciclo
  presionMin1 = 0;
  presionMax2 = 0;
  presionMin2 = 0;
}

void pin_ISR() {    //Interrupt para leer el boton de reset
  ResetAlarma = 1;
}

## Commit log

2020-05-11 diseños laser
2020-05-14 File update
    [Testing.xlsx]
2020-05-19 Update and testing
    [Adaptador 25 a 22 manguera mascara v2.stl, Respirador AMBU DQ3D 18 y 20mm.stl, Testing.xlsx]
2020-05-22 Update .ino y testing
    [Testing.xlsx]
2020-05-22 updated testing
    [Testing.xlsx]
2020-07-19 Update 19 Julio
    [Jalador 8mm para eje 6mm ver2.stl, Respirador COVID19NIC.xlsx, potknob_parametric sin tornillo.stl]
2021-01-30 last updates
    [Respirador COVID19NIC.xlsx]
